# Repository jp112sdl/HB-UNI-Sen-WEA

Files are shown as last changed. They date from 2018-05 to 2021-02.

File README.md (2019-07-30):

# Selbstbau-868MHz-Funk-Wetterstation (mit Netzteilbetrieb) für HomeMatic  

### Die Dokumentation zu diesem Projekt findet ihr im -> [Wiki](https://github.com/jp112sdl/HB-UNI-Sen-WEA/wiki).

**Hinweise:**
  - **die aktuelle Version des Source-Codes setzt mind. [Addon Version V1.20](https://github.com/jp112sdl/HB-UNI-Sen-WEA/wiki/Addon) oder höher voraus!**
  - **vor dem Flashen des Codes immer auf die neueste AskSinPP(-master) Bibliothek aktualisieren**

Besten Dank an [Christoph Herrmann](https://www.facebook.com/hermi.leipzig) für die Zusendung seines Nachbaus ([Thingiverse-Link](https://www.thingiverse.com/thing:3173141)):
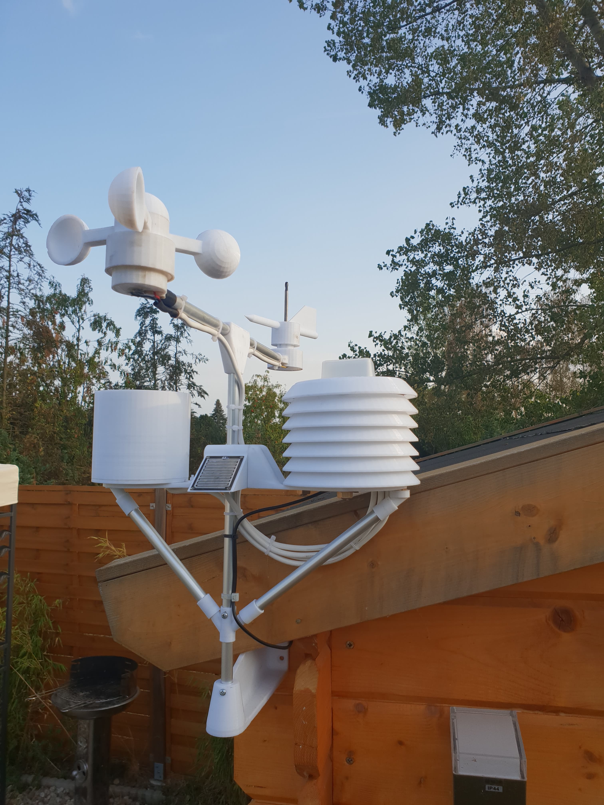
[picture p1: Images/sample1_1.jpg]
complete

<br/>
Hier meine Version unter Verwendung eines Huger Regenmengenmessers und noch vor der Installation des Regendetektors:
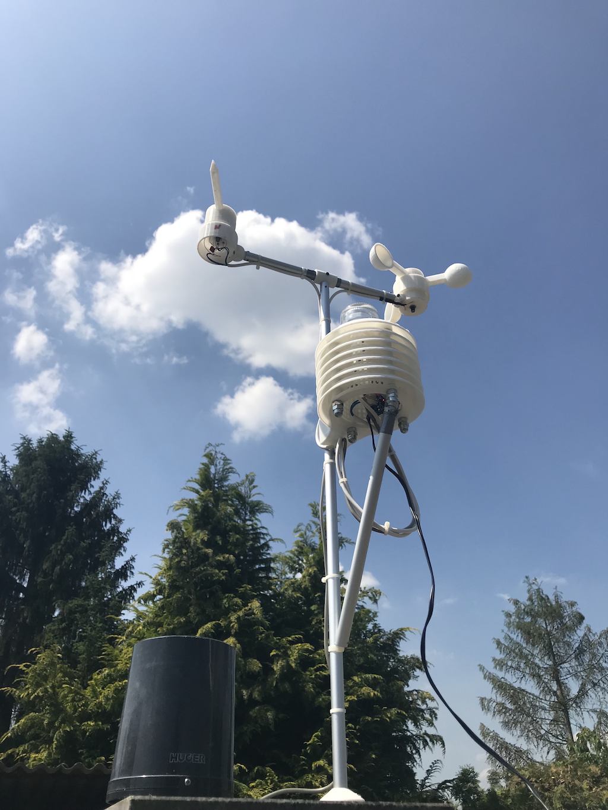
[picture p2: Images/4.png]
complete_jp


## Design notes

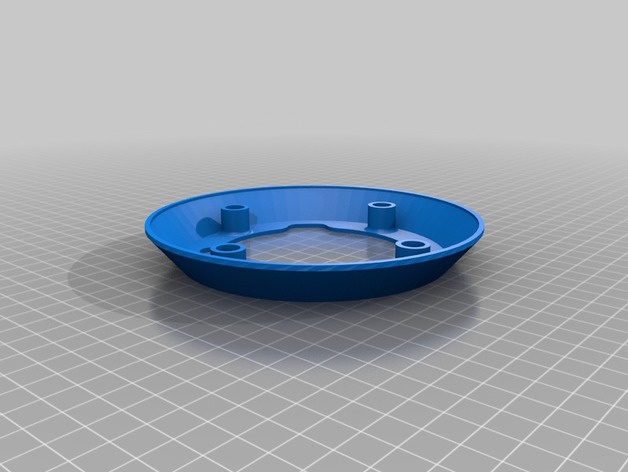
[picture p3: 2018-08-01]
3DDruck/Luftdaten_Stevensson_screen/images/de5c749b48ccad6f2da1c18631324c17_preview_featured.jpg

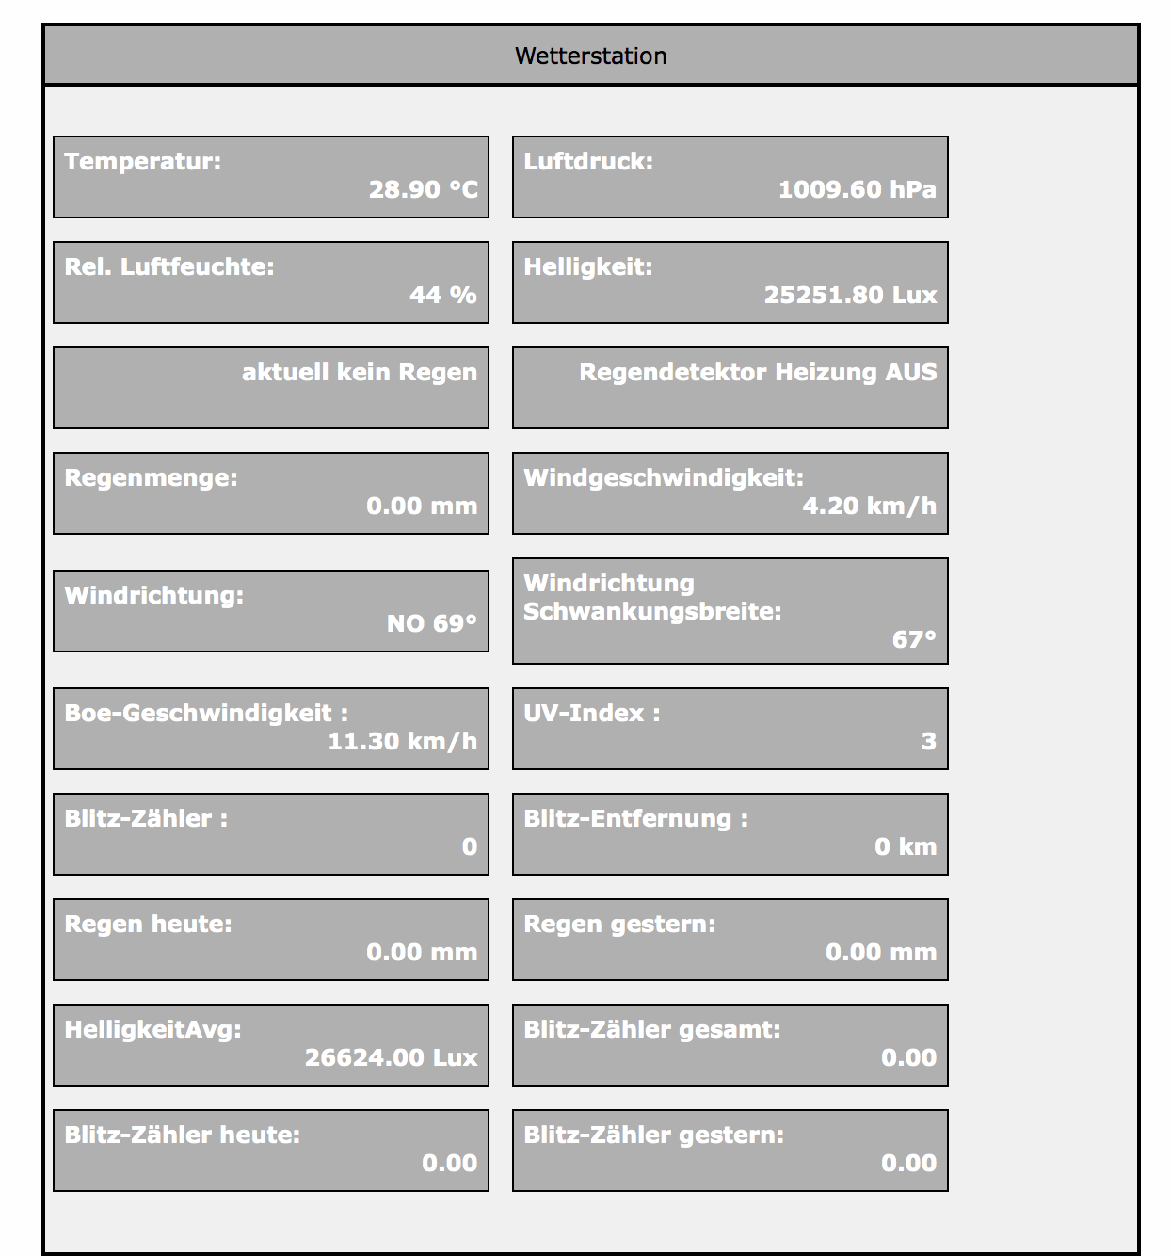
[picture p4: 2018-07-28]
Images/CCU_Bedienung.png

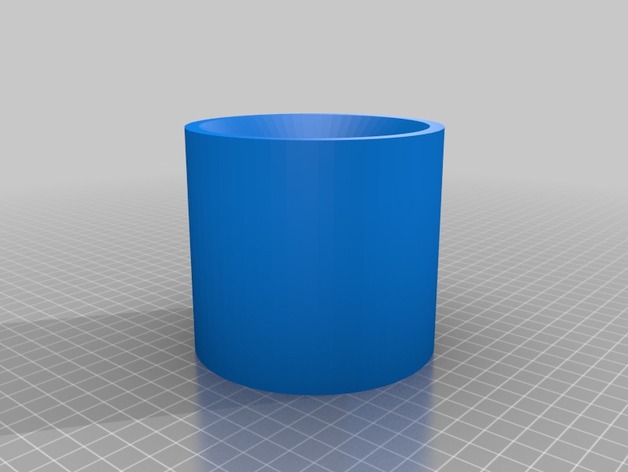
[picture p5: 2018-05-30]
3DDruck/LTB_Weather_Station/images/117a4e0169dc935ad4cb069c9b1e4cbd_preview_featured.jpg

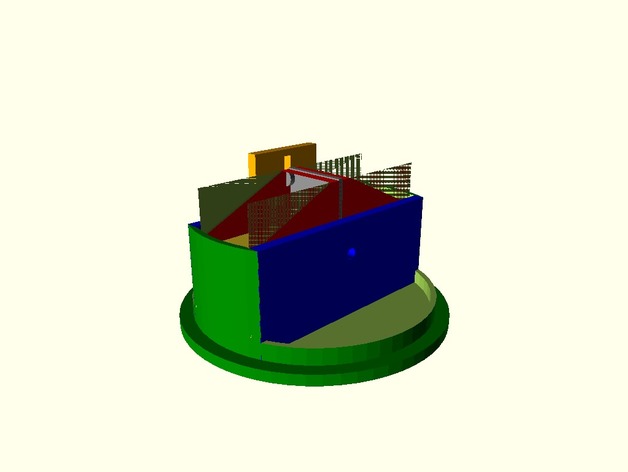
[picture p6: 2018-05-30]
3DDruck/LTB_Weather_Station/images/5851a940cc2cf8ce6b7ae1dae2f9f374_preview_featured.jpg

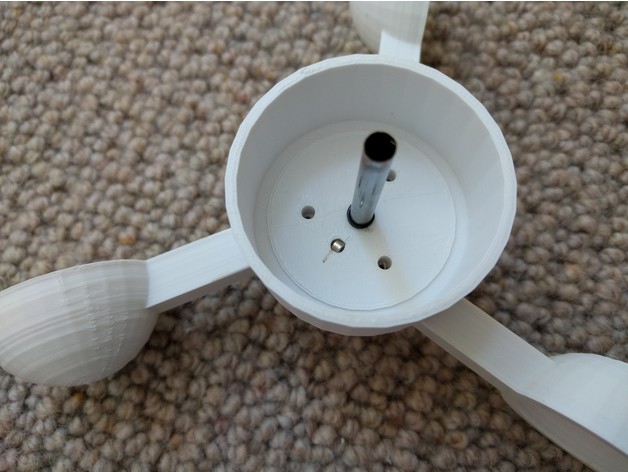
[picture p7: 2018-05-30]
3DDruck/LTB_Weather_Station/images/2c7b42b0f8cd26165a07a06924028e5b_preview_featured.jpg

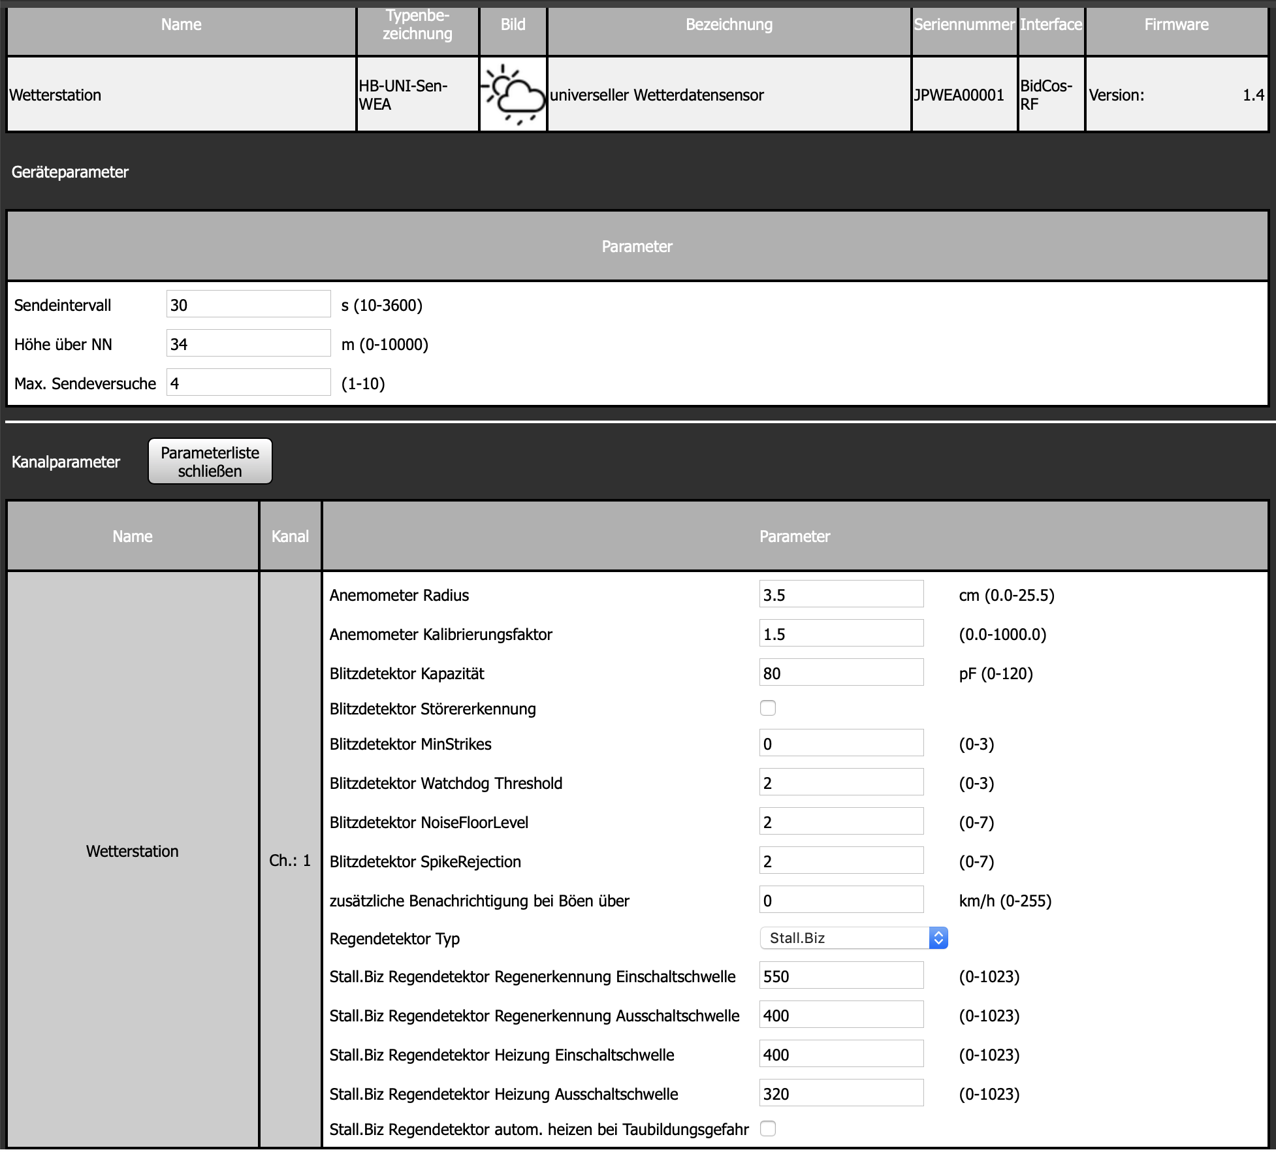
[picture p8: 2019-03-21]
Images/CCU_Einstellungen.png

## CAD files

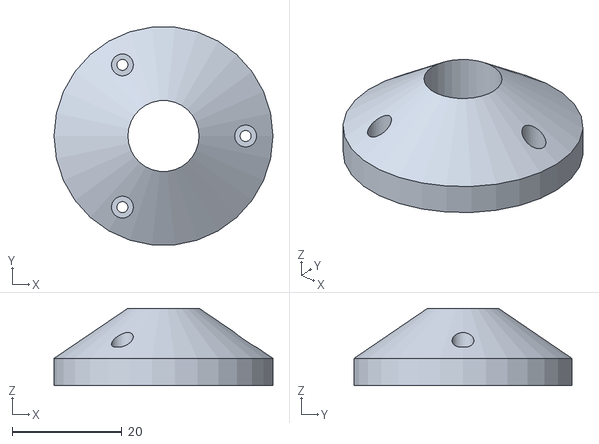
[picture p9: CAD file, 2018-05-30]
3DDruck/LTB_Weather_Station/files/42Fram_Base.stl
40.0 x 39.8 x 14.2

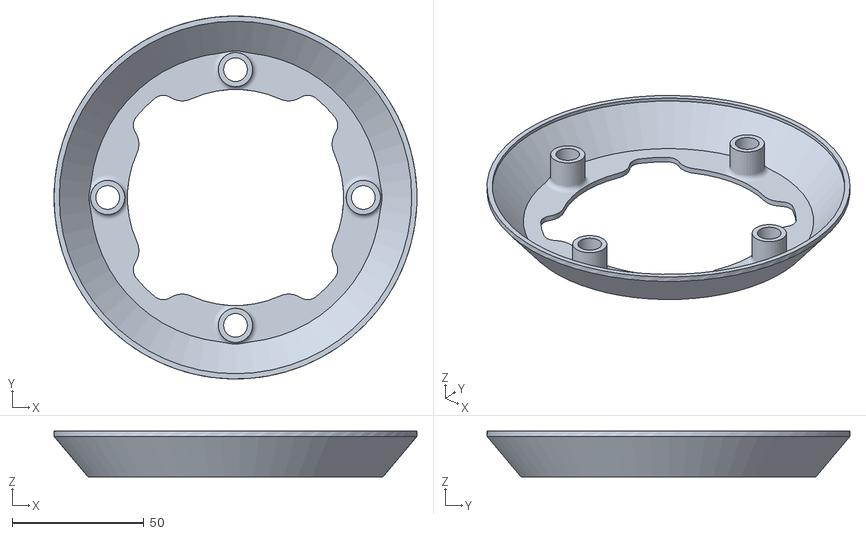
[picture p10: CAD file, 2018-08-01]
3DDruck/Luftdaten_Stevensson_screen/files/middle_part_x6.STL
137.7 x 137.7 x 17.3

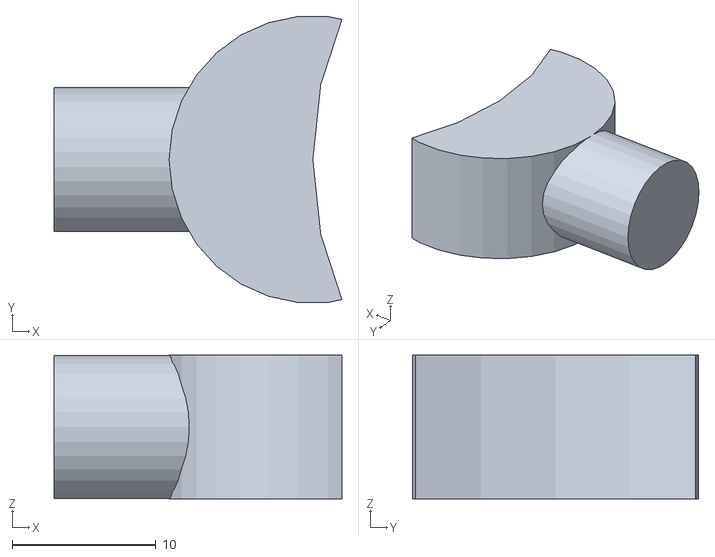
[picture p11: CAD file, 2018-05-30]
3DDruck/LTB_Weather_Station/files/13Direc_bracket.stl
20.0 x 19.9 x 10.0

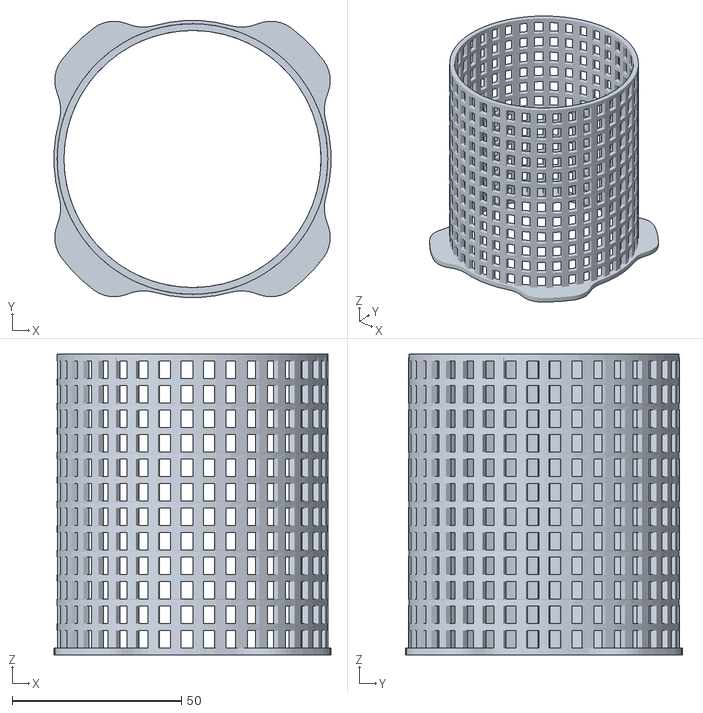
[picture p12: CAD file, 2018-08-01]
3DDruck/Luftdaten_Stevensson_screen/files/sds011_holder_x1.STL
81.9 x 81.9 x 89.0

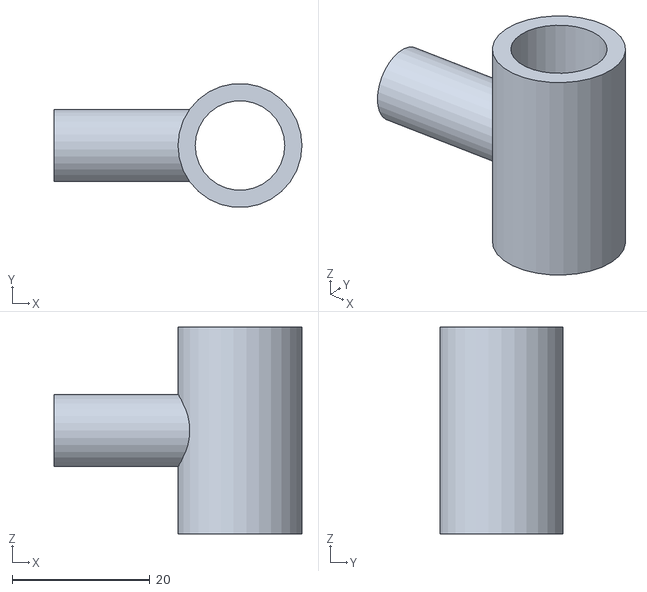
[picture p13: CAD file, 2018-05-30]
3DDruck/LTB_Weather_Station/files/41Fram_T_piece.stl
36.0 x 17.9 x 30.0

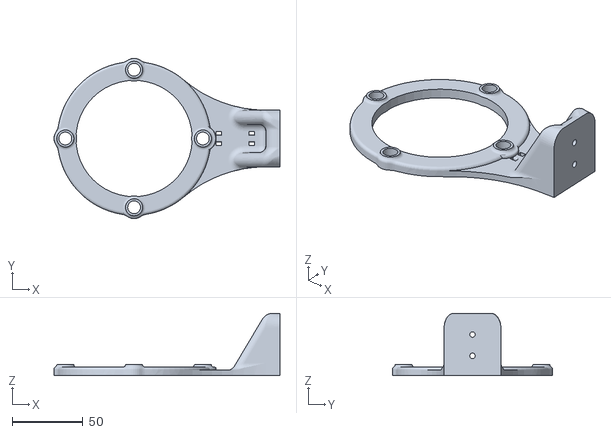
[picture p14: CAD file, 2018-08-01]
3DDruck/Luftdaten_Stevensson_screen/files/wall_bottom_part_x1.STL
159.3 x 112.9 x 44.0

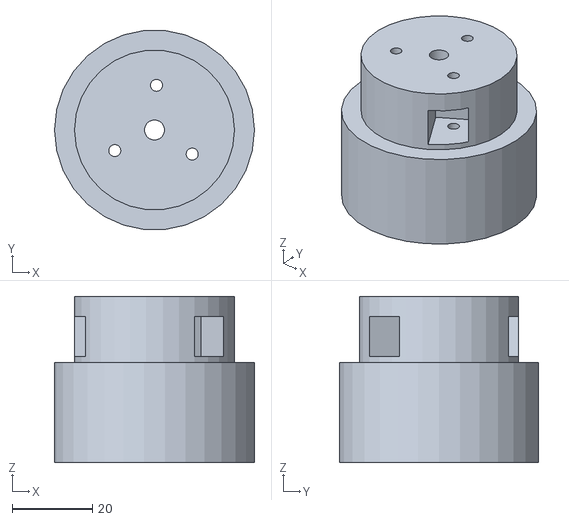
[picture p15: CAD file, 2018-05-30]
3DDruck/LTB_Weather_Station/files/02Anem_center.stl
50.0 x 49.7 x 41.5

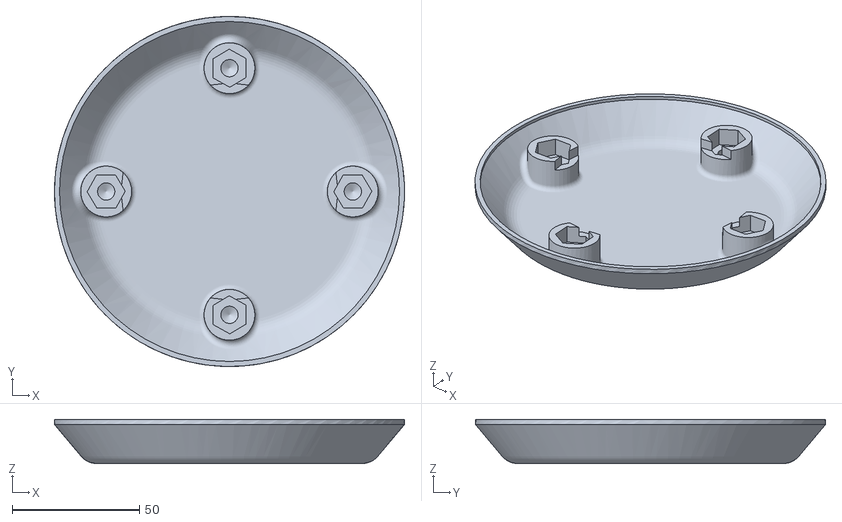
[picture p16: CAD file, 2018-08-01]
3DDruck/Luftdaten_Stevensson_screen/files/top_part_x1.STL
137.7 x 137.7 x 17.3

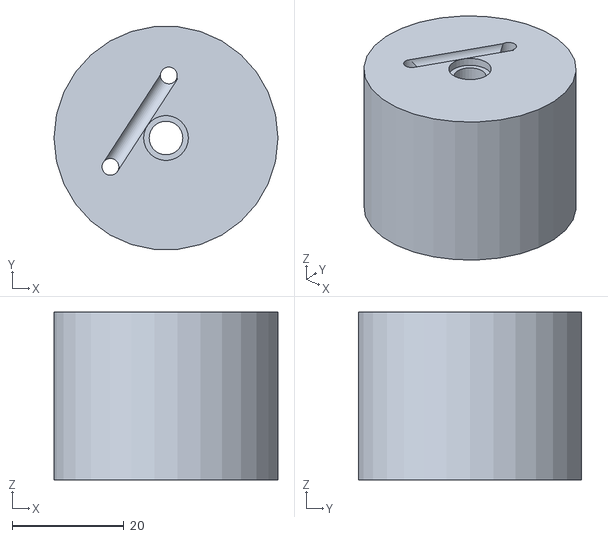
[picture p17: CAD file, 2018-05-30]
3DDruck/LTB_Weather_Station/files/03Anem_Base.stl
40.0 x 39.8 x 30.0

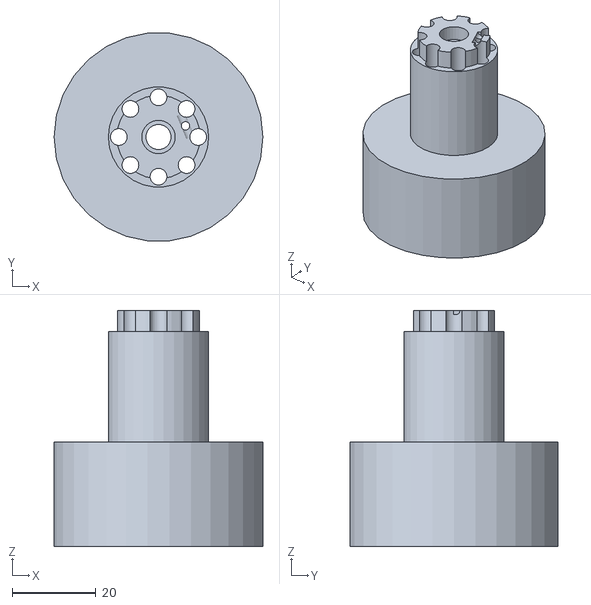
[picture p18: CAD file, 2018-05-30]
3DDruck/LTB_Weather_Station/files/12Direc_base.stl
50.0 x 49.7 x 56.5

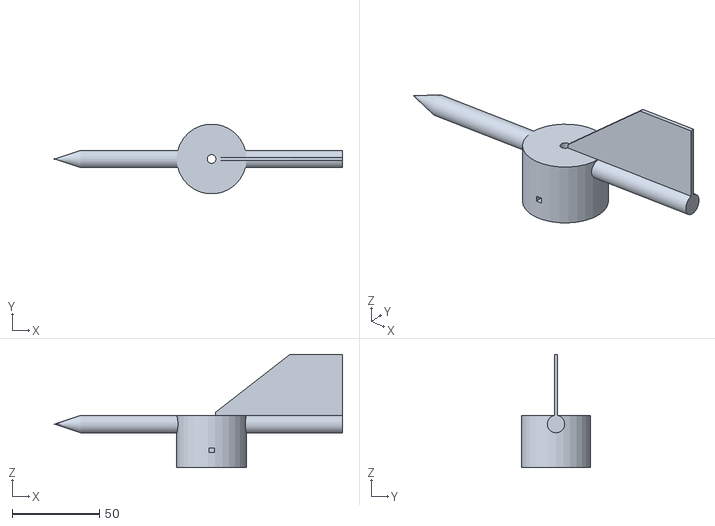
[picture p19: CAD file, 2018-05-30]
3DDruck/LTB_Weather_Station/files/11Direc_pointer.stl
165.0 x 39.8 x 65.0

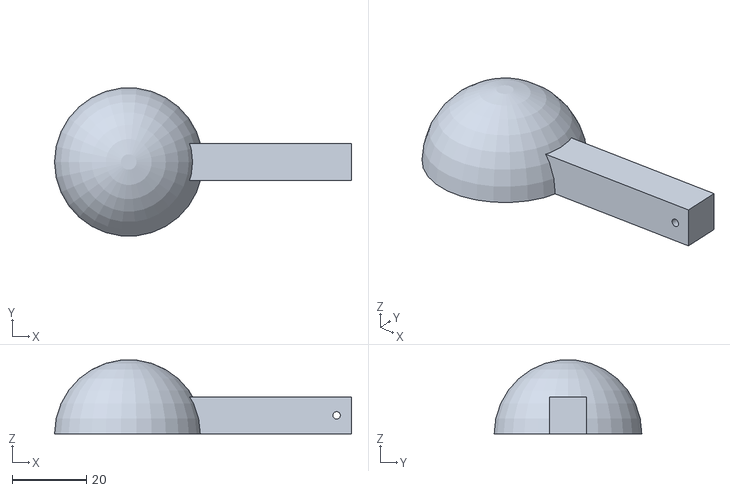
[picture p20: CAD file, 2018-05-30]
3DDruck/LTB_Weather_Station/files/01Anem_Cup.stl
80.0 x 39.8 x 19.9

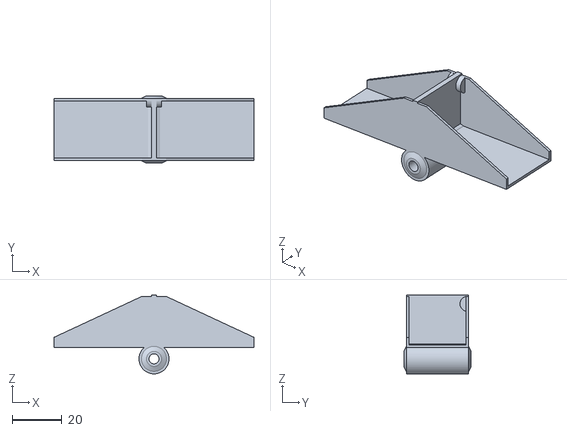
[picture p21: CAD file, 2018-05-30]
3DDruck/LTB_Weather_Station/files/31Rain_FlipFlop.stl
80.0 x 27.0 x 31.5

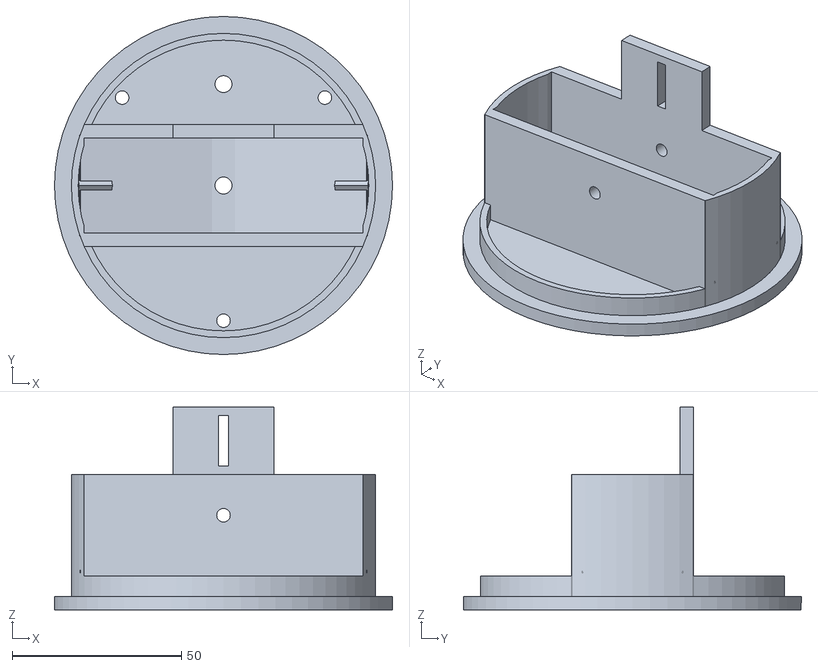
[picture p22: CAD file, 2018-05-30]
3DDruck/LTB_Weather_Station/files/32Rain_Base.stl
100.0 x 100.0 x 60.0

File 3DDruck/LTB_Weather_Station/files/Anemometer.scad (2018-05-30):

//LTB Weather in 3D
//Anemometer and Wind Direction

$fn=30;
//Non-Printable Extras
//Neodymium Magnet, cylinder  2mm thick, 3mm diam
//Red Switches, 14mm long 2mm diam
//Thrust bearings, 8mm OD, 5 mmID, 2.5mm thick
//Rods for the bearings 5mm OD, rescued brass antenna tubing is ideal!
//Heat shrink tubing to make a small sleeve to adjust height off bearings

//Make the shape of the front of the vane
module prism(l, w, h){
  polyhedron(
    points=[[0,0,0], [l,0,0], [l,w,0], [0,w,0], [0,w,h], [l,w,h]],
    faces=[[0,1,2,3],[5,4,3,2],[0,4,5,1],[0,3,4],[5,2,1]]
   );
}

module windvane(){
	difference(){
		union(){
			rotate([0,90,0]) cylinder(150,5,5,true); //main rod
			translate([-82.5,0,0])rotate([0,90,0]) cylinder(15,0,5,true); //pointy tip
			translate([45,-1,0]) cube([30,2,40]); //vane_1
			rotate([0,0,-90])  translate([-1,0,5]) prism(2,45, 35);//vane_2
			translate([0,0,-10]) cylinder(30,20,20,true); //mounting bracket
		}
		//This next dimension hollows the innner skirt of the windvane
		//It controls how close you can get the magnet to the reed switches
		//The magnet needs N-S to be vertical aligned with the reed switches
		//If it is not close enough or strong enough it will not reliably
		//trigger the both reed switches when positioned halfway between two.
		//This effect allows 16 directions to be obtained from 8 switches.
		//You may need to experiment a bit here to make it reliable.
		translate([0,0,-15]) cylinder(30,13.2,13.2,true); //mount cap inner
		cylinder(60,2.5,2.5,true); //mounting spindle axle hole 5mm diam 
		//magnet mount, radial distance is adjustable for multiple reed 'hits'
		//hitting 2 reed switches at a time doubles resolution from 8 to 16
		 translate([0,-11,-15]) rotate([0,0,90]) cube([20,3.1,2.6],true); 
	}
}

module dirbasesupport(){
  difference(){
   union(){
		translate([0,0,2.5]) cylinder(5,10,10,true); //axle mount top
 		color("red") translate([0,0,-15]) cylinder(30,12,12,true); //mount cap inner
	 translate([0,0,-39]) //move bottom skirt
	 difference(){
		 color("red") cylinder(25,25,25,true); //outer skirt
		 translate([0,0,-2]) cylinder(23,23,23,true); //inner skirt
	 }
	}
		cylinder(70,3,3,true); //spindle hole,6mm ID for 5mm axle
	  translate([0,0,3]) cylinder(4,4,4,true); //top hole for bearing
	  translate([0,0,-28]) cylinder(4,4,4,true); //bottom hole for bearing 	 	
		rotate([0,0,22.5]) translate([7,0,-10]) cylinder(60,1,1,true);//Relay common wire
		rotate([90,180,22.5]) translate([-7,-5,0]) cylinder(6,1,1,true);//Relay common wire
 
	   for(rrelay = [0 : 45 : 360])
		  //rotate([90,rrelay,0]) translate([25,10,0]) 
		rotate([0,0,rrelay]) translate([9.5,0,-10]) cylinder(60,2,2,true);//Relays mounts
	 }
}

//Print three of these separately
module cup(){
	color("blue")
	difference(){
		translate([-66,0,0]) //radiate from center
		difference(){
			union(){
				sphere(20); //outer wall
				translate([35,0,5]) cube([50,10,10],true); //support arm
			}
			sphere(17); //inner space
			translate([0,0,-10]) cube([40,40,20],true); //chop off what we don't need
		}
		rotate([90,0,0]) translate([-10,5,0])  cylinder(20,1,1,true); //screw mount
	}
}

module cups3mount(){
	difference(){
	union(){
		cylinder(20,20,20,true);
	 translate([0,0,-19]) //move bottom skirt
	 difference(){
		 cylinder(25,25,25,true); //outer skirt
		 translate([0,0,-2]) cylinder(23,23,23,true); //inner skirt
	 }
 }
		cups3(); //just used to create and align holes for cups
		rotate([0,0,174]) translate([-10,5,0]) cylinder(40,1.5,1.5,true); //screw mount
		rotate([0,0,54]) translate([-10,5,0]) cylinder(40,1.5,1.5,true); //screw mount
		rotate([0,0,294]) translate([-10,5,0]) cylinder(40,1.5,1.5,true); //screw mount
		cylinder(40,2.5,2.5,true);//spindle axle 5mm OD
		translate([0,-8,-10]) cube([2,3,4],true);//magnet hole, N-S is aligned tangential to circumference, ie magnetic force lines are along the switch reeds
		}
}	

//now combine all three into one module, to set up holes in mount base
module cups3(){
	rotate([90,0,0])cup();
	rotate([90,0,120])cup();
	rotate([90,0,240])cup();
}

module cuprotormount(){
	difference(){
		cylinder(30,20,20,true);
		rotate([0,0,54]) translate([-10,5,0]) cylinder(40,1.5,1.5,true); //reed relay mount
		rotate([0,0,294]) translate([-10,5,0]) cylinder(40,1.5,1.5,true); //reed relay mount
		rotate([0,90,57]) translate([-15,5.5,0]) cylinder(20,1.5,1.5,true); //reed relay slot for mounting

		cylinder(40,3,3,true);//6mm ID spindle bearing shaft, for a 5mm axle
	  translate([0,0,14.5]) cylinder(2,4,4,true); //top hole for bearing 8mmOD
	  translate([0,0,-14.5]) cylinder(2,4,4,true); //bottom hole for bearing 8mm OD
	}
}

//Glue this to the side of the speed indicator for a mouning option
module bracketSpeed(){
	difference(){	
		cylinder(10,10,10,true);
		translate([20,0,0]) cylinder(10,20,20,true);
	}
	translate([-13,0,0]) rotate([90,0,90,]) cylinder(10,5,5,true);
}

//Glue this to the side of the direction indicator for a mouning option
module bracketDirection(){
	difference(){	
		cylinder(10,10,10,true);
		translate([25,0,0]) cylinder(10,25,25,true);
	}
	translate([-13,0,0]) rotate([90,0,90,]) cylinder(10,5,5,true);
}

//Use this to mount the aluminium crossbar on a vertical aluminium tube
module Tpiece(){
	difference(){	
		union(){
			cylinder(30,9,9,true);
			translate([-17,0,0]) rotate([90,0,90,]) cylinder(20,5.25,5.25,true);
		}
		translate([0,0,0]) cylinder(30,6.5,6.5,true);
	}
}

//Vertical mount for the aluminium tube onto the baseboard
module Tframebase(){
	difference(){
		union(){
	translate([0,0,2.5]) cylinder(5,20,20,true);
	translate([0,0,10]) cylinder(10,20,5.25,true);
		}
	rotate([0,0,0,]) cylinder(30,6.5,6.5,true);
		
	 rotate([0,0,0]) translate([15,0,10]) cylinder(10,2,2,true);	
	rotate([0,0,120]) translate([15,0,10])cylinder(10,2,2,true);	
	rotate([0,0,240]) translate([15,0,10])cylinder(10,2,2,true);
		
	 rotate([0,0,0]) translate([15,0,10]) cylinder(30,1,1,true);	
	rotate([0,0,120]) translate([15,0,10])cylinder(30,1,1,true);	
	rotate([0,0,240]) translate([15,0,10])cylinder(30,1,1,true);	
}
}

module direction(){
difference(){
  union(){
		translate([0,0,6]) windvane(); //direction indicator
		translate([0,0,0]) dirbasesupport(); //mount for direction indicator
	}
	//translate([-220,0,-200]) cube([400,400,400]); //shows cutaway
 }
}

module speed(){
//cup(); //one cup, print three times
difference(){
union(){ 
	cups3(); //three cups in place, DO NOT print this
  cups3mount(); //mount support for cups
  translate([0,0,-28]) color("gold") cuprotormount(); //speed base and bearings holder
	}
		//translate([-220,0,-200]) cube([400,400,400]); //shows cutaway
}
}

//Rendering visually
//Use these to see the parts "in-situ"

//Wind Speed Parts
translate([-60,0,0]) speed();
//translate([-20,0,0]) bracketSpeed();

//Wind Direction Parts
//translate([60,0,0]) direction();
//translate([5,0,0]) bracketDirection();

//Mounting Frame Parts
//Tpiece();
//Tframebase();

//STL List (render each separately and export as .stl)

//Wind speed parts (Anemometer)
  //cup(); //print 3 of these
  //cups3mount();
  //cuprotormount();
	//bracketSpeed();
//Wind direction parts
	//windvane();
	//dirbasesupport();
	//bracketDirection();
//Frame parts
	//Tpiece();
	//Tframebase();

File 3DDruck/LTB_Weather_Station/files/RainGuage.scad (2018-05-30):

//LTB weather in 3D
//Bucket tipping rain-guage

//Non-Printable Extras
//Neodymium Magnet, cylinder  2mm thick, 3mm diam
//Red Switch, 14mm long 2mm diam
//Rod for the axle 1.5 mm OD, rescued brass antenna tubing is ideal!
//2 rings of plastic tubing to put on opposite ends of tipping bucket axle.

$fn=60;
hy=5;  //hysteresis
//Main support base for bucket, drainage and electronics
module Rbase(){
	difference(){
		color("green") union(){
			cylinder(4,50,50); //main base
			cylinder(8,45,45); //outer base rim
			translate([0,0,4]) cylinder(4,40,40); //main middle base
			translate([0,0,20]) cylinder(40,45,45,true); //main base outer cylinder
		}
		translate([0,0,25]) cylinder(40,43,43,true); //main base inner cylinder
		translate([30,26,0]) cylinder(20,2,2,true);  //base mounting/levelling hole
		translate([-30,26,0]) cylinder(20,2,2,true); //base mounting/levelling hole
		translate([0,-40,0]) cylinder(20,2,2,true);  //base mounting/levelling hole
		rotate([0,0,90]) cylinder(10,2.5,2.5,true);  //small water drainhole
		translate([0,30,0]) rotate([0,0,90]) cylinder(10,2.5,2.5,true);  //small wire exit hole
		translate([0,40,0]) rotate([0,90,90]) cylinder(20,2.5,2.5,true);  //small wire exit tunnel
	}
}
module Rffsupport(){
	color("blue")
	difference(){
		translate([0,0,20]) cube([82.5,4,40],true); //side support
		translate([0,0,23+hy]) rotate([90,0,0]) cylinder(5,2,2,true);//locating semi-circle
	}
}

module drainramps(){
	//drain the water our of the central hole
	color("yellow") translate([-23,0,8]) rotate([0,10,0])cube([39.5,30,1],true);
	color("yellow") translate([23,0,8]) rotate([0,-10,0])cube([39.5,30,1],true);
	//projections to stop lip of bucket being held by water tension
	color("red") translate([-38,0,11]) rotate([45,10,0])cube([10,2,2],true);
	color("red") translate([38,0,11]) rotate([45,-10,0])cube([10,2,2],true);
	
}

module Rrelaysupport(){
	//place the reed switch in the gap and heat the wires on it to melt into the 
	//plastic and hold it in place, or just glue it there.
	color("orange")
	difference(){
		translate([0,30,50]) cube([30,4,20],true); //Plate for mounting reed switch
		translate([0,30,50]) rotate([0,90,0]) cube([15,5,3],true); //hole for reed switch
	}
}

module Rmainbase(){
	difference(){
		Rbase();
	  translate([0,0,30]) cube([82.4,124,40],true);//big cutaway
	}
		translate([0,-16,0]) Rffsupport();
		translate([0,+16,0]) Rffsupport();
		translate([0,-14,0]) Rrelaysupport();
		drainramps();
}

//Flip Flop tipping bucket
module Rflipflop(){
	difference(){
		union(){
			difference(){
				//begin with
				translate([0,0,10]) color("red") cube([80,25,20],true); //main body
				//take these out
				translate([-20,0,35]) rotate([0,155,0]) cube([80,25,40],true); 
				translate([20,0,35]) rotate([0,-155,0]) cube([80,25,40],true); //subtract top half of cube
				translate([0,0,10]) color("red") cube([80,23,20],true); //main body
			}
		//add these in
		cube([80,25,1],true);	//the flat base of tipping cups
		color("gray")  translate([0,0,8]) cube([2,25,25],true); //divider plate
		translate([0,0,-hy]) rotate([90,0,0]) cylinder(25,6,6,true); //outer axle bearing
		translate([0,13,-hy])  rotate([90,0,0]) cylinder(1,3,3,true); //washer A
		translate([0,-13,-hy])  rotate([90,0,0]) cylinder(1,3,3,true); //washer B
		translate([0,13,-hy])  rotate([90,0,0]) cylinder(1,3,5,true); //washer A slope
		translate([0,-13,-hy])  rotate([90,0,0]) cylinder(1,5,3,true); //washer B slope
		color("grey")	translate([0,12,17]) rotate([0,90,0])cylinder(6,3,3,true); //support for the magnet	
			}
	//take these out	
	translate([0,0,-hy]) rotate([90,0,0]) cylinder(29,2,2,true); //inner axle
	translate([-5,12.5,12.5],true) cube([10,10,10]); //removes excess magnet support
	translate([0,12,17]) cube([4,3,2],true);//magnet hole, NB N-S is parallel to the reed switch, ie field lines run along the reed switches
		
	}
}

module funnel(){
	translate([0,0,5])
		difference(){
			color("red") cylinder(90,50,50); //main base
			cylinder(90,45,45); //main base
		}
	difference(){
		translate([0,0,55]) cylinder(40,2,48);
		translate([0,0,58]) cylinder(40,2,48);
		translate([0,0,55]) cylinder(10,2,2);
	}
}

//Main parts
Rmainbase();
translate([0,0,38-hy])	rotate([0,0,0]) Rflipflop(); //flip flop tipping
//Rflipflop();
difference(){
	//funnel();
	//uncomment for a "demonstration funnel" to show people how it works
	//rotate([0,0,90]) translate([10,-100,0]) cube([100,200,100]);  //for demo cutaway
}

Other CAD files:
3DDruck/LTB_Weather_Station/files/34Rain_PartFunnel.stl
3DDruck/LTB_Weather_Station/files/33Rain_Funnel.stl
3DDruck/LTB_Weather_Station/files/04Anem_bracket.stl

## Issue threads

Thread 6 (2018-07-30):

Schaltplan mit HB-UNI-SEN-PCB

Athemis, 2018-07-30:
Hallo,

ersteinmal ein großes Dankeschön für dieses inspirierende Projekt :) Aus den Bildern geht hervor, dass Du das HB-UNI-SEN-PCB von Alex Reinert verwendest? Wäre es möglich, dass Du in der Dokumentation auch die Verschaltung anhand dieses Boards einfügst? Ich bin mir sicher, dass ich mir das vermutlich (unter großer Fehleranfälligkeit) auch selbst zusammenreimen kann, aber wozu das Rad neu erfinden...

Besten Dank!

jp112sdl, 2018-07-30:
Mahlzeit!

Ja, ich habe dieses Board im Einsatz.
Aber ich würde es für **dieses** Projekt nicht empfehlen.
 _(Das Board an sich ist Klasse, wenn man ein paar I²C Sensoren und/oder analoge Eingänge nutzen möchte.)_
Aufgrund der mittlerweile von der ursprünglichen Wetterstation entstandenen Menge an Sensoren, reichen die auf dem Board ausgeführten Pins bei weitem nicht mehr aus, so dass ich den AS3935 teilweise und den Regendetektor bereits vollständig an die Pro Mini Pinleiste anlöten musste.

Vielleicht erstellt ja jemand ein Board, an das die verwendeten Sensoren komplett angeschlossen werden können. Darüber würde auch ich mich sehr freuen. 😄

LG,
Jérôme

Athemis, 2018-07-30:
Alles klar. Ich hatte beinahe befürchtet, dass nicht genügend Pins nach außen geführt werden. Da ich aber noch ein paar von den Boards hier herumfliegen habe, werde ich vermutlich dennoch eines als Grundlage nehmen und dann ggf. die Sensoren direkt am Arduino anflanschen :grinning:

LG, Alex

jp112sdl, 2018-07-30:
Spätestens wenn mir das 3. Mal die Drähte abgebrochen sind, denke ich noch mal über eine eigene Platine nach 🙄
Aber ich hoffe, dass sich nun nichts mehr an der Hardware ändert.
Vom 328P-Flash-Platz her ist eh kaum noch was frei und das Datentelegramm ist in seiner Länge auch aufs letzte Byte ausgereizt. Es wären maximal noch 1-2 logische Zustände, die übertragen werden könnte. Aber da fällt mir auch gerade nichts ein, was dafür infrage käme. 😃

☀️ Grüße ☀️

jp112sdl, 2018-07-31:
Ich habe gestern Abend noch ein wenig mit Alex geplaudert und er setzt sich mal ran, eine Platine für dieses Projekt hier zu entwerfen, bzw. die HB-UNI-SEN-PCB abzuändern.
Wenn es was Neues gibt, melde ich mich hier wieder.

Athemis, 2018-07-31:
Klasse, das wäre natürlich die optimale Lösung :) Ich bin schon sehr gespannt.

jp112sdl, 2018-08-08:
So, [hier](https://github.com/jp112sdl/HB-UNI-Sen-WEA/wiki/Platine) wäre dann das Ergebnis.
😄

Athemis, 2018-08-08:
Super! Dann weiß ich schon einmal, was es jetzt zu bestellen gilt... :smile:

jp112sdl, 2018-08-08:
Ich habe soeben einen Stapel in Auftrag gegeben.
Du kannst von mir eine (oder auch mehrere) zum Selbstkostenpreis + Versand bekommen (sobald sie eingetroffen sind).

Athemis, 2018-08-17:
Hatte zu dem Zeitpunkt selbst schon eine Hand voll geordert ;-)

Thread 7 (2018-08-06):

fehlende Libs

Xento, 2018-08-06:
Hi,
ich möchte mir auch soeine Wetterstation bauen und habe versucht den Sketch zu compilern.
Leider fehlen die Bibliotheken für
#include <sensors/Max44009.h>
#include <sensors/Veml6070.h>

Für Max44009 konnte wahrscheinlich die richtige Lib finden, allerdings will Veml6070 nicht.
Ich nutze die Arduino IDE zum compilern.
Könntest du Links zu den verwendeten Bibliotheken reinstellen?

jp112sdl, 2018-08-06:
Hi,

lade dir bitte mal die aktuelle master der AskSinPP Library.
Dort sind die Sensorklassen für den Max44009 und Veml6070 mit drin.
Es werden **keine** gesonderten Bibliothek benötigt.

Siehe auch: https://github.com/jp112sdl/HB-UNI-Sen-WEA/wiki/Code

Xento, 2018-08-06:
Ah super. Dann muss ich mal alles aktualisieren.

Closed 2018-08-06.

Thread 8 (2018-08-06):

Frage: Wie funktioniert die Böenerkenung

Xento, 2018-08-06:
Wie genau funktioniert die Böenerkennung?
Wird nur alle x Sekunden gemessen oder wird alle x Sekunden geprüft ob eine Böe da war?
Will damit meine Markiese bei Böen einfahren lassen.

jp112sdl, 2018-08-06:
5 Sekunden lang werden die Impulse gezählt und daraus die Geschwindigkeit ermittelt.
Die Windgeschwindigkeit hingegen ist der Mittelwert aller "5-Sekunden-Geschwindigkeiten", die im eingestellten Sendeintervall ermittelt wurden.

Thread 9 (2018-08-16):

BIDI bei WeatherEventMsg?

Xento, 2018-08-16:
Ist er richtig so, dass die WeatherEventMsg bidirektional gesendet werden?
Seitdem ich einen Windsensor gebaut habe ist auch bei 60 sekündiger Meldung der DC der CCU ziehmlich angestiegen.
Will mir noch einen zweiten Wettersensor mit allen Sensoren bauen, dann währe die CCU schon ziehmlich an ihrere Grenze.

jp112sdl, 2018-08-16:
Echt? 😱
Ich sende alle 30 Sekunden und da passiert nix am DC.
Eigentlich wird nur jede [20. Meldung per BIDI gesendet, sonst per BCAST](https://github.com/jp112sdl/HB-UNI-Sen-WEA/blob/7250f011d05615f5691bec8c287be622bd283e45/HB-UNI-Sen-WEA.ino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).
Oder hab ich einen Denkfehler?

Aber bei mir liegt der DC konstant zwischen 5-9%

jp112sdl, 2018-08-16:
![Uploading Bildschirmfoto 2018-08-16 um 10.51.04.png…]()

Habs gerade noch mal gecheckt. Arbeitet korrekt.

Xento, 2018-08-16:
Ok, soweit hab ich noch nicht in den Code geschaut.
Hatte nur das BIDI bei der Message gesehen.
Das BIDI wird zurückgesetzt wenn man das per broadcast sendet.
Dann muss ich mal weiter rumprobieren warum der DC nun so hoch ist bei mir ...

jp112sdl, 2018-08-16:
Ja genau, `broadcastPeerEvent()` sendet automatisch per BCAST.

Closed 2018-08-16.

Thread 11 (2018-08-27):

Kalibrierung für Ersatz-Anemometer für die Funk-Wetterstation WS1080 und WS3080

Xento, 2018-08-27:
Ich habe mal die Kalibrierungsdaten für das oben genannte Ersatzteil von ELV ausgeklügelt.
Die Daten habe ich mit Hilfe der Freetec Wetterstation von Pearl ermittelt.
Diese ich bis auf das Funkprotokoll baugleich mit der WS1080, daher ist es auch das gleiche Windrad.

Damit immer der gleiche Wind auf das Windrad trifft, habe ich das Anemometer abwechselnd mit der Wetterstation und dem Homematic Sensor verbunden und die Werte verglichen.
Folgende Werte sind dabei rausgekommen:
Radius: 7 cm
Kalbrierungsfaktor: 1.5

Vielleicht kann man eine Liste mit Werten für verschiedene Anemometer bereitstellen.
Wenn jemand keinen Windmesser oder eine andere Referenz hat, ist es quasi unmöglich die richtigen Werte zu finden.

jp112sdl, 2018-08-27:
Besten Dank! Bin noch am Überlegen, wo ich diese Informationen am besten platziere...

jp112sdl, 2018-08-28:
https://github.com/jp112sdl/HB-UNI-Sen-WEA/wiki/Kalibrierungsdaten_Sensoren

Closed 2018-08-28.

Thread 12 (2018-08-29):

Nachrichten werden mit NACK von anderem AsksinPP-Aktor beantwortet

Xento, 2018-08-29:
Ich habe gerade zufällig festgestellt, dass irgendwie komische Nachrichten gesendet werden.

Der Wettersensor ist mit meinem RolloAktor (auch mit AskSinPP) gepeert so dass dieser runter fährt wenn ne Windböhe kommt.

Hier ein Auszug aus der Log vom Rolloaktor:
```
-> 0D 05 A0 53 F1D002 5932AF 41 00 00 C7  - 254183
<- 0A 05 80 02 5932AF F1D002 80  - 254298
-> 0D 05 A0 53 F1D002 5932AF 41 00 00 C7  - 254337
<- 0A 05 80 02 5932AF F1D002 80  - 254459
-> 0D 05 A0 53 F1D002 5932AF 41 00 00 C7  - 254498
<- 0A 05 80 02 5932AF F1D002 80  - 254619
-> 0D 05 A0 53 F1D002 5932AF 41 00 00 C7  - 254652
<- 0A 05 80 02 5932AF F1D002 80  - 254769
-> 0D 05 A0 53 F1D002 5932AF 41 00 00 C7  - 254803
<- 0A 05 80 02 5932AF F1D002 80  - 254918
-> 0D 05 A0 53 F1D002 5932AF 41 00 00 C7  - 254957
<- 0A 05 80 02 5932AF F1D002 80  - 255078
-> 0C 06 A2 41 F1D002 5932AF 01 01 C8  - 255281
jumpToTarget: 6 1
setDestLevel: 0
Switch from 06 to 04
getNextState: 4
Switch from 04 to 05
<- 0E 06 80 02 5932AF F1D002 01 01 00 40 58  - 255401
getNextState: 5
calcDriveTime: 420 - 0 - 20
Switch from 05 to 09
DOWN - 255823
getNextState: 9
Switch from 09 to 06
STOP - 257853
```

Der Asksin Aktor schickt scheinbar irgendwas falsches auf diese Nachricht zurück ...

Xento, 2018-08-29:
Ah ich habe gerade festgestellt, das 0A 05 80 02 5932AF F1D002 80 ein NACK ist.
Das währe jetzt was für @pa-pa aber sollte, danach nicht weiter versucht werden die Nachricht erneut zu senden?

jp112sdl, 2018-08-29:
Hmm, wäre es dann evtl. eher ein Ticket für die AskSinPP Lib?

Von der Wetterstation kommt als COND_VALUE `C8` (200).

Ich hab die Wetterstation bisher nur mit einem originalen HM Zwischenstecker gepeert und da ist das Verhalten korrekt.

Falls du die Möglichkeit hast, könntest du als Gegenprobe mal einen Tastensender peeren. Der verhält sich m.W. genau so und sendet 200 an den Aktor.
Dann könntest du dort mal schauen, wie der Reply vom Rollladenaktor aussieht.

jp112sdl, 2018-08-29:
Ich wollte gerade fragen, welchen Stand dein eingesetzter Wetterstations-Sketch hat 😄
Denn der geht nur, wenn du die aktuelle AskSinPP nutzt mit eben genanntem Commit.
Die ExtraMessages werden seither nämlich nur noch direkt an die Zentrale gesendet.

Xento, 2018-08-29:
Werd ich morgen mal machen ;-)

Xento, 2018-08-30:
Soo, AskSinPP war schon auf dem aktuellen Stand, nur der Sketch nicht.

Hab da noch nen paar Offtopic Punkte:
1. Ich sollte mich glaube ich mal mit dem OTA-Bootloader beschäftigen, dann muss ich mich nicht immer an die Geräte stöpseln.
Funktioniert das eigentlich mit der CCU?

2. Mir ist aufgefallen, dass der Sketch für einen Arduino mit dem normalen Bootloader zu groß ist.
Die IDE sagt es währen 102% belegt.
Wenn man das Debugging deaktiviert dann sind noch 93% frei.
Zum Glück habe ich auf diesem Arduino schon den OptiBootloader drauf.

jp112sdl, 2018-08-30:
> Ich sollte mich glaube ich mal mit dem OTA-Bootloader beschäftigen, dann muss ich mich nicht immer an die Geräte stöpseln.
Funktioniert das eigentlich mit der CCU?

Ja, aber ob der Arduino per Funkbefehl in den Bootloader-Modus wechselt, weiß ich nicht.
Ich habe da nichts weiter implementiert und auch bisher nur 1-2 Mal mit OTA experimentiert.
Da ich gern nach dem Flashen noch kurz die Debugmeldungen sehen möchte, bleibe ich bei der Turnschuhvariante. 😄

> Mir ist aufgefallen, dass der Sketch für einen Arduino mit dem normalen Bootloader zu groß ist. Die IDE sagt es währen 102% belegt.

Welche Arduino IDE Version benutzt du?
Mit der 1.8.5 wird der Sketch zu groß. Ich nutze die 1.8.1 -> damit passt alles. Ohne Veränderung des Bootloaders.

> Wie bringt man der CCU bei, dass das Gerät eine neue Firmwareversion hat?
Musste nachdem ich das Addon aktualisiert hatte, den Sensor einmal ablernen und wieder anlernen.

Drüberlernen würde ausreichen, um die Versionsinformation an sich upzudaten.
Aber wenn neue Werte-Parameter hinzukommen, bleibt leider nix weiter übrig, als das Gerät komplett neu anzulernen. Das ist aber ein "Problem" der ReGa.

Closed 2018-09-04.

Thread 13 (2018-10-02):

slightly better parameter check of pwmval overflow in raindetector_heater

harvey637, 2018-10-02:
Hallo Jerome,
ist das optimal?

in funktion raindetector_heater:
...
if (State == true) {
  if pwmval < 255) pwmval = pwmval + 51;
} else
...

Alles richtig, es wird bei jedem Durchlauf pwmval um 51 erhöht, also 0 - 51 - 102 - 153 - 204 - 255.
Also passt < 255, weil ja nach dem 5. Durchlauf keine Erhöhung mehr stattfindet.

Will man da spielen könnte ein "#define PWMHEATER_DELTA 51" das ganze variabel gestalten,
also den Anstieg der Erwärmung z.b. flacher einstellen. Dann spätestens wäre es besser, etwa mit

#define PWMHEATER_DELTA 30 // zusätzliche Erwaermung der Regendetektorheizung je Durchlauf
(RAINDETECTOR_CHECK_INTERVAL)

...
if ((pwmval + PWMHEATER_DELTA) > 255) {
   pwmval = 255;
} else {
   pwmval = pwmval + PWMHEATER_DELTA;
}
...

das ganze (im Sketch) konfigurierbar und korrekt geprüft zu gestalten.
Sorry, sind wieder ein paar Byte mehr :-( Aber auch ohne define finde ich das if ... then ... else besser.
cu
Harvey

jp112sdl, 2018-10-02:
Ja, das kann jeder spielen wie er möchte.
Grundanliegen der PWM-Ansteuerung war, dass die Spannung beim Einschalten der Heizung nicht einbricht.

Btw.: Würde die Bedingung `(pwmval + PWMHEATER_DELTA) > 255` überhaupt erfüllt werden, so lange `pwmval` ein `uint8_t` ist?

Und wegen der paar Byte mehr -> wenn man einen kleineren (oder gar keinen) Bootloader auf den Pro Mini flasht, hat man noch gut Luft nach oben.

harvey637, 2018-10-02:
Hallo Jerome,
danke für die schnelle Antwort!

Vermutung: das "pwmval + PWMHEATER_DELTA" ist erstmal unabhängig von uint_8, ich test das mal, nur zum eigenen Verstandnis.

Genauso habe ich das mit dem langsamen Anheizen auch vermutet (Grund für ansteigenden PWM).
Eine Kleinigkeit fällt mir noch ein:
Könnte es sinnvoll sein, die zeitliche Länge des Heizens zu beschränken? Eventuell
liegt ein Blatt drauf oder eine Frucht ist drauf gefallen und geplatzt. Auch der Taupunkt könnte
ziemlich lange im HEAT_DEWFALL_T bleiben. In der Summe sicherlich verschmerzbar (Stromkosten),
aber der Sensor freut sich bestimmt drüber. Ich denke für mich auch über einen reinen
Regensensor nach, der dann ohne device.xml funktioniert und Heizung per Funk
geschaltet werden kann, ein von xxx Projektchen.
Neben dem (erfolgreich abgeschlossenen) LCD-Anzeige von Temperatursensoren und dem
ebenfalls (aber sehr quick_n_dirty) abgeschlossenen Dallas-Sensoren mit SENSOR_ID (aus user_byte)
anstatt der SENSOR_ADDR. Beispiele dazu in DallasTemperature gefunden.
Danke und ciao
Harvey

jp112sdl, 2018-10-02:
> Könnte es sinnvoll sein, die zeitliche Länge des Heizens zu beschränken?

Ist mir bisher noch gar nicht in den Sinn gekommen.

> aber der Sensor freut sich bestimmt drüber.

Mit ~50°C von unten dauerhaft beheizt zu werden, ist denke ich kein Problem für die Platine.

>  Auch der Taupunkt könnte ziemlich lange im HEAT_DEWFALL_T bleiben.

Ja, manchmal die halbe Nacht bei mir. Aber dann bleibt halt die Heizung an. Ist mir lieber, als eine Regen-Falschmeldung (die ich bisher noch **nie** hatte!) zu bekommen.

>  Ich denke für mich auch über einen reinen
Regensensor nach, der dann ohne device.xml funktioniert und Heizung per Funk
geschaltet werden kann, ein von xxx Projektchen.

Ja, sollte kein Problem sein den HM-Sen-RD-O nachzubilden.
Und der hat ja einen Kanal zum Schalten der Heizung.

Closed 2018-10-02.

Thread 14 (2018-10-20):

Abdeckung für UV Sensor VEML6070

spaceduck518, 2018-10-20:
wie habt ihr die die wasserfeste Abdeckung für den UV Sensor realisiert? Alle mir bekannten transparenten Kunststoffe filtern UV Strahlung, da dürfte am Sensor nicht mehr viel ankommen.

jp112sdl, 2018-10-20:
Hi,

für allgemeine Diskussionen bitte das Homematic Forum benutzen.
Es gibt hier einen Beitrag zum dem Wettersensor:
https://homematic-forum.de/forum/viewtopic.php?f=76&t=44245&start=390
Du kannst auch gern einen neuen Beitrag erstellen.

Hier erreichst du vorrangig nur mich als Entwickler...
Ich benutze eine kleines Gewürzglas.
Gabs mal als Adventkalender:
https://www.discounto.de/Angebot/Erlesene-Gewuerz-Selection-Adventskalender-955697/

LG,
Jérôme

Closed 2018-10-20.

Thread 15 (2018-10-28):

Regenmelder Sensorplatine anschließen

Alveran81, 2018-10-28:
Hallo,

bin gerade dabei die Wetterstation nachzubauen. Habe zunächst Arduino, BME280, CC1101 und Anemometer angeschlossen und einen Funktionstest gemacht. Werte kommen sauber auf der Homematic an.
Ich habe mir wie empfohlen diesen Regensensor gekauft. https://www.stall.biz/produkt/regenmelder-sensorplatine
Leider finde ich keinen Anschlussplan oder technische Daten. Wird dieser mit 5V betrieben und wie verbinde ich den Arduino damit?  Laut Schaltplan steht was von Pin9. Soll ja nicht die ganze zeit beheizt werden sondern nur wenn es regnet.
Also verstehe ich richtig, Dauerplus liegt immer an, die Masse für über den Transistor der an Pin neun hängt geschalten und dann müssen doch eigentllich noch zwei Messleitung verbunden werden?
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

jp112sdl, 2018-10-28:
Hi,

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

Es geht der
- **rot-weiße** Draht an **+ Heizung**, der
- **orange-weiße** an **- Heizung**,
- **schwarz** (GND) an **A vom Sensor** und
- **orange** geht an **B vom Sensor**.

Bei der Heizung wird wie schon richtig erkannt, +5V dauerhaft anliegen und die Heizung über den NPN Transistor an Pin 9 bei Bedarf eingeschaltet.

Alveran81, 2018-10-28:
Jetzt habe ich es verstanden. Vielen Dank.
Vielleicht kann man das in der Grafik noch ergänzen (schwarz (GND) an A vom Sensor und
orange geht an B vom Sensor.)

jp112sdl, 2018-10-28:
Ich dachte, die Grafik (Sensorfläche an schwarz/orange) wäre ausreichend. ;)

Alveran81, 2018-10-28:
War mir nicht ganz klar und da ich kein Datenblatt zum Sensor gefunden habe wollte ich lieber nochmal fragen bevor es einmal kurz raucht. 😁

jp112sdl, 2018-10-28:
A und B sind nicht leitend miteinander verbunden, da kann nix passieren.
Bei der Heizung passiert bei Verpolung einfach gar nix... 😄

Closed 2018-10-29.

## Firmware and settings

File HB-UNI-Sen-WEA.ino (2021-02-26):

//- -----------------------------------------------------------------------------------------------------------------------
// AskSin++
// 2016-10-31 papa Creative Commons - http://creativecommons.org/licenses/by-nc-sa/3.0/de/
// some parts (BME280 measurement) from HB-UNI-Sensor1
// 2018-05-11 Tom Major (Creative Commons)
// 2018-05-21 jp112sdl (Creative Commons)
//- -----------------------------------------------------------------------------------------------------------------------
// #define NDEBUG   // disable all serial debuf messages
// #define NSENSORS // if defined, only fake values are used
#define SENSOR_ONLY

#define  EI_NOTEXTERNAL
#include <EnableInterrupt.h>
#include <SPI.h>
#include <AskSinPP.h>
#include <Register.h>

#include <MultiChannelDevice.h>
#include <sensors/Max44009.h>
#include <sensors/Veml6070.h>
#include "Sensors/Sens_Bme280.h"
#include "Sensors/Sens_As3935.h"
#include "Sensors/Sens_As5600.h"
#include "Sensors/VentusW132.h"
//#include "Sensors/PCF8574_WindDir.h"

#define CONFIG_BUTTON_PIN                    8     // Anlerntaster-Pin

////////// REGENDETEKTOR
//bei Verwendung der Regensensorplatine von stall.biz (https://www.stall.biz/produkt/regenmelder-sensorplatine)
#define RAINDETECTOR_STALLBIZ_SENS_PIN       A3   // Pin, an dem der Kondensator angeschlossen ist (hier wird der analoge Wert für die Regenerkennung ermittelt)
#define RAINDETECTOR_STALLBIZ_CRG_PIN        4    // Pin, an dem der Widerstand für die Kondensatoraufladung angeschlossen is
#define RAINDETECTOR_STALLBIZ_HEAT_PIN       9    // Pin, an dem der Transistor für die Heizung angeschlossen ist
#define RAINDETECTOR_STALLBIZ_HEAT_DEWFALL_T 20   // Temperaturschwelle bei aktiviertem "automatisch Heizen bei Erreichen des Taupunkts"; default = 20 (heizen bei +/- 2,0°C um den Taupunkt)

//bei Verwendung eines Regensensors mit H/L-Pegel Ausgang
#define RAINDETECTOR_PIN                     9    // Pin, an dem der Regendetektor angeschlossen ist
#define RAINDETECTOR_PIN_LEVEL_ON_RAIN       LOW  // Pegel, wenn Regen erkannt wird

#define RAINDETECTOR_CHECK_INTERVAL          5     // alle x Sekunden auf Regen prüfen
/////////////////////////////////////////////////////////////////////

#define WINDSPEEDCOUNTER_PIN                 5     // Anemometer
#define RAINQUANTITYCOUNTER_PIN              6     // Regenmengenmesser


#define AS3935_ENVIRONMENT                   ::Sens_As3935<>::AS3935_ENVIRONMENT_OUTDOOR
#define AS3935_IRQ_PIN                       3     // IRQ Pin des Blitzdetektors
#define AS3935_CS_PIN_OR_ADDR                7     // SPI: CS Pin / I2C: Address (default: 0x03)

#define WINDDIRECTION_PIN                    A2    // Pin, an dem der Windrichtungsanzeiger (RESISTORS oder PULSE) angeschlossen ist
#define WINDDIRECTION_USE_RESISTORS
//#define WINDDIRECTION_USE_PULSE

//#define WINDDIRECTION_USE_AS5600
//#define WINDDIRECTION_USE_PCF8574

//#define WINDDIRECTION_USE_VENTUSW132
//#define VENTUSW132_PIN_N                     A0    // Pins für den Anschluss der
//#define VENTUSW132_PIN_O                     A1    // 4 Photodioden
//#define VENTUSW132_PIN_S                     A2    // des Ventus W132
//#define VENTUSW132_PIN_W                     A6    // Ersatz-Windmessers

//                             N                      O                           S                           W
//entspricht Windrichtung in ° 0 , 22.5 , 45 , 67.5 , 90 , 112.5 , 135 , 157.5 , 180 , 202.5 , 225 , 247.5 , 270 , 292.5 , 315 , 337.5
#ifdef WINDDIRECTION_USE_PULSE
const uint16_t WINDDIRS[] = { 70 ,   78 , 86 , 94   , 102,  108  , 116 ,    0  , 8   , 16    , 24  , 32    , 40  ,   48  , 56  , 62 };
#endif
#ifdef WINDDIRECTION_USE_RESISTORS
const uint16_t WINDDIRS[] = { 58 ,   74 , 52 , 115  , 97 ,  328  , 302 ,  790  , 559 , 663   , 187 , 205   , 163 ,  420  , 129 , 153 };
#endif
#if defined(WINDDIRECTION_USE_VENTUSW132) || defined(WINDDIRECTION_USE_PCF8574)
           //direction index  0   1   2    3    4    5    6    7
const uint16_t WINDDIRS[] = { 0, 45, 90, 135, 180, 225, 270, 315 };
#endif
#ifdef WINDDIRECTION_USE_AS5600
const uint16_t WINDDIRS[] = {0,0,0,0,0,0,0,0,0,0,0,0,0,0,0,0};
#endif

#define WINDSPEED_MEASUREINTERVAL_SECONDS    5     // Messintervall (Sekunden) für Windgeschwindigkeit / Böen
//////////////////////////////////////////////////////////////////////////////////////////////////////////////////////////////////////////


//some static definitions
#define WINDSPEED_MAX              0x3FFF
#define GUSTSPEED_MAX              0x7FFF
#define RAINCOUNTER_MAX            0x7FFF
#define STORM_COND_VALUE_LO        100
#define STORM_COND_VALUE_HI        200
#define PEERS_PER_CHANNEL          4

using namespace as;

volatile uint32_t _rainquantity_isr_counter = 0;
volatile uint16_t _wind_isr_counter = 0;

void rainquantitycounterISR() {
  _rainquantity_isr_counter++;
}
void windspeedcounterISR() {
  _wind_isr_counter++;
}

enum eventMessageSources {EVENT_SRC_RAINING, EVENT_SRC_HEATING, EVENT_SRC_GUST};

const struct DeviceInfo PROGMEM devinfo = {
  {0xF1, 0xD0, 0x02},        // Device ID
  "JPWEA00002",           	 // Device Serial
  {0xF1, 0xD0},            	 // Device Model
  0x14,                   	 // Firmware Version
  as::DeviceType::THSensor,  // Device Type
  {0x01, 0x01}             	 // Info Bytes
};

// Configure the used hardware
typedef AskSin<NoLed, NoBattery, Radio<LibSPI<10>, 2>> Hal;
Hal hal;

class WeatherEventMsg : public Message {
  public:
    void init(uint8_t msgcnt, int16_t temp, uint16_t airPressure, uint8_t humidity, uint32_t brightness, bool israining, bool isheating, uint16_t raincounter,  uint16_t windspeed, uint8_t winddir, uint8_t winddirrange, uint16_t gustspeed, uint8_t uvindex, uint8_t lightningcounter, uint8_t lightningdistance) {
      Message::init(0x1a, msgcnt, 0x70, BIDI | RPTEN, (temp >> 8) & 0x7f, temp & 0xff);
      pload[0] = (airPressure >> 8) & 0xff;
      pload[1] = airPressure & 0xff;
      pload[2] = humidity;
      pload[3] = (brightness >>  16) & 0xff;
      pload[4] = (brightness >>  8) & 0xff;
      pload[5] = brightness & 0xff;
      pload[6] = ((raincounter >> 8) & 0xff) | (israining << 7);
      pload[7] = raincounter & 0xff;
      pload[8] = ((windspeed >> 8) & 0xff) | (winddirrange << 6);
      pload[9] = windspeed & 0xff;
      pload[10] = winddir;
      pload[11] = ((gustspeed >> 8) & 0xff) | (isheating << 7);
      pload[12] = gustspeed & 0xff;
      pload[13] = (uvindex & 0xff) | (lightningdistance << 4);
      pload[14] = lightningcounter & 0xff;
    }
};

class ExtraEventMsg : public Message {
  public:
    void init(uint8_t msgcnt, bool israining, bool isheating, uint16_t gustspeed) {
      Message::init(0x0d, msgcnt, 0x53, BIDI | RPTEN, 0x41, (israining & 0xff) | (isheating << 1));
      pload[0] =  (gustspeed >> 8) & 0xff;
      pload[1] =  gustspeed & 0xff;
    }
};

DEFREGISTER(Reg0, MASTERID_REGS, DREG_TRANSMITTRYMAX, 0x20, 0x21, 0x22, 0x23)
class SensorList0 : public RegList0<Reg0> {
  public:
    SensorList0(uint16_t addr) : RegList0<Reg0>(addr) {}

    bool updIntervall (uint16_t value) const {
      return this->writeRegister(0x20, (value >> 8) & 0xff) && this->writeRegister(0x21, value & 0xff);
    }
    uint16_t updIntervall () const {
      return (this->readRegister(0x20, 0) << 8) + this->readRegister(0x21, 0);
    }

    bool height (uint16_t value) const {
      return this->writeRegister(0x22, (value >> 8) & 0xff) && this->writeRegister(0x23, value & 0xff);
    }
    uint16_t height () const {
      return (this->readRegister(0x22, 0) << 8) + this->readRegister(0x23, 0);
    }

    void defaults () {
      clear();
      updIntervall(60);
      height(0);
      transmitDevTryMax(6);
    }
};

DEFREGISTER(Reg1, 0x01, 0x02, 0x03, 0x04, 0x05, 0x06, 0x07, 0x08, 0x09, 0x0a, 0x0b, 0x0c, 0x0d, 0x0e, 0x0f, 0x10, 0x11, 0x12, 0x13, 0x14, 0x15, 0x16)
class SensorList1 : public RegList1<Reg1> {
  public:
    SensorList1 (uint16_t addr) : RegList1<Reg1>(addr) {}
    bool AnemometerRadius (uint8_t value) const {
      return this->writeRegister(0x01, value & 0xff);
    }
    uint8_t AnemometerRadius () const {
      return this->readRegister(0x01, 0);
    }

    bool AnemometerCalibrationFactor (uint16_t value) const {
      return this->writeRegister(0x02, (value >> 8) & 0xff) && this->writeRegister(0x03, value & 0xff);
    }
    uint16_t AnemometerCalibrationFactor () const {
      return (this->readRegister(0x02, 0) << 8) + this->readRegister(0x03, 0);
    }

    bool LightningDetectorCapacitor (uint8_t value) const {
      return this->writeRegister(0x04, value & 0xff);
    }
    uint8_t LightningDetectorCapacitor () const {
      return this->readRegister(0x04, 0);
    }

    bool LightningDetectorMinStrikes (uint8_t value) const {
      return this->writeRegister(0x12, value & 0xff);
    }
    uint8_t LightningDetectorMinStrikes () const {
      return this->readRegister(0x12, 0);
    }

    bool LightningDetectorWatchdogThreshold (uint8_t value) const {
      return this->writeRegister(0x13, value & 0xff);
    }
    uint8_t LightningDetectorWatchdogThreshold () const {
      return this->readRegister(0x13, 0);
    }

    bool LightningDetectorNoiseFloorLevel (uint8_t value) const {
      return this->writeRegister(0x14, value & 0xff);
    }
    uint8_t LightningDetectorNoiseFloorLevel () const {
      return this->readRegister(0x14, 0);
    }

    bool LightningDetectorSpikeRejection (uint8_t value) const {
      return this->writeRegister(0x15, value & 0xff);
    }
    uint8_t LightningDetectorSpikeRejection () const {
      return this->readRegister(0x15, 0);
    }

    bool LightningDetectorDisturberDetection () const {
      return this->readBit(0x05, 0, true);
    }
    bool LightningDetectorDisturberDetection (bool v) const {
      return this->writeBit(0x05, 0, v);
    }

    bool ExtraMessageOnGustThreshold (uint8_t value) const {
      return this->writeRegister(0x06, value & 0xff);
    }
    uint8_t ExtraMessageOnGustThreshold () const {
      return this->readRegister(0x06, 0);
    }

    bool StormUpperThreshold (uint8_t value) const {
      return this->writeRegister(0x07, value & 0xff);
    }
    uint8_t StormUpperThreshold () const {
      return this->readRegister(0x07, 0);
    }

    bool StormLowerThreshold (uint8_t value) const {
      return this->writeRegister(0x08, value & 0xff);
    }
    uint8_t StormLowerThreshold () const {
      return this->readRegister(0x08, 0);
    }

    bool RaindetectorStallBizHiThresholdRain (uint16_t value) const {
      return this->writeRegister(0x09, (value >> 8) & 0xff) && this->writeRegister(0x0a, value & 0xff);
    }
    uint16_t RaindetectorStallBizHiThresholdRain () const {
      return (this->readRegister(0x09, 0) << 8) + this->readRegister(0x0a, 0);
    }
    bool RaindetectorStallBizLoThresholdRain (uint16_t value) const {
      return this->writeRegister(0x0b, (value >> 8) & 0xff) && this->writeRegister(0x0c, value & 0xff);
    }
    uint16_t RaindetectorStallBizLoThresholdRain () const {
      return (this->readRegister(0x0b, 0) << 8) + this->readRegister(0x0c, 0);
    }
    bool RaindetectorStallBizHiThresholdHeater (uint16_t value) const {
      return this->writeRegister(0x0d, (value >> 8) & 0xff) && this->writeRegister(0x0e, value & 0xff);
    }
    uint16_t RaindetectorStallBizHiThresholdHeater () const {
      return (this->readRegister(0x0d, 0) << 8) + this->readRegister(0x0e, 0);
    }
    bool RaindetectorStallBizLoThresholdHeater (uint16_t value) const {
      return this->writeRegister(0x0f, (value >> 8) & 0xff) && this->writeRegister(0x10, value & 0xff);
    }
    uint16_t RaindetectorStallBizLoThresholdHeater () const {
      return (this->readRegister(0x0f, 0) << 8) + this->readRegister(0x10, 0);
    }

    bool RaindetectorSensorType (uint8_t value) const {
      return this->writeRegister(0x11, value & 0xff);
    }
    uint8_t RaindetectorSensorType () const {
      return this->readRegister(0x11, 0);
    }

    bool RaindetectorStallBizHeatOnDewfall () const {
      return this->readBit(0x16, 0, true);
    }
    bool RaindetectorStallBizHeatOnDewfall (bool v) const {
      return this->writeBit(0x16, 0, v);
    }

    void defaults () {
      clear();
      AnemometerRadius(65);
      AnemometerCalibrationFactor(10);
      LightningDetectorCapacitor(80);
      LightningDetectorDisturberDetection(true);
      ExtraMessageOnGustThreshold(0);
      StormUpperThreshold(0);
      StormLowerThreshold(0);
      RaindetectorSensorType(0);
      RaindetectorStallBizHiThresholdRain(750);
      RaindetectorStallBizLoThresholdRain(500);
      RaindetectorStallBizHiThresholdHeater(500);
      RaindetectorStallBizLoThresholdHeater(400);
      RaindetectorStallBizHeatOnDewfall(true);
      LightningDetectorMinStrikes(0);
      LightningDetectorSpikeRejection(2);
      LightningDetectorWatchdogThreshold(2);
      LightningDetectorNoiseFloorLevel(2);
    }
};

class WeatherChannel : public Channel<Hal, SensorList1, EmptyList, List4, PEERS_PER_CHANNEL, SensorList0>, public Alarm {
    int16_t       temperature;
    uint16_t      airPressure;
    uint8_t       humidity;
    uint32_t      brightness;
    bool          israining;
    bool          isheating;
    uint16_t      raincounter;
    uint16_t      windspeed;
    uint16_t      gustspeed;
    uint16_t      uvindex;
    uint8_t       lightningcounter;
    uint8_t       lightningdistance;

    uint8_t       winddir;
    uint8_t       winddirrange;

    uint16_t      stormUpperThreshold;
    uint16_t      stormLowerThreshold;

    bool          initComplete;
    bool          initLightningDetectorDone;
    uint8_t       short_interval_measure_count;
    uint8_t       israining_alarm_count;

    Sens_Bme280                 bme280;
    Veml6070<VEML6070_1_T>      veml6070;
    MAX44009<>                  max44009;
#ifdef WINDDIRECTION_USE_AS5600
    Sens_As5600                 as5600;
#endif
#ifdef WINDDIRECTION_USE_VENTUSW132
    VentusW132<VENTUSW132_PIN_N, VENTUSW132_PIN_O, VENTUSW132_PIN_S, VENTUSW132_PIN_W> ventus;
#endif
#ifdef WINDDIRECTION_USE_PCF8574
    PCF8574_WindDir<0x38> pcf;
#endif

  public:
#ifdef __SENSORS_AS3935_h__
    Sens_As3935<AS3935_CS_PIN_OR_ADDR, AS3935_IRQ_PIN> as3935;
#endif
  public:
    WeatherChannel () : Channel(), Alarm(seconds2ticks(60)), temperature(0), airPressure(0), humidity(0), brightness(0), israining(false), isheating(false), raincounter(0), windspeed(0), gustspeed(0), uvindex(0), lightningcounter(0), lightningdistance(0), winddir(0), winddirrange(0), stormUpperThreshold(0), stormLowerThreshold(0), initComplete(false), initLightningDetectorDone(false), short_interval_measure_count(0), israining_alarm_count(0), wind_and_uv_measure(*this), lightning_and_raining_check(*this)  {}
    virtual ~WeatherChannel () {}

    class WindSpeedAndUVMeasureAlarm : public Alarm {
        WeatherChannel& chan;
      public:
        WindSpeedAndUVMeasureAlarm (WeatherChannel& c) : Alarm (seconds2ticks(WINDSPEED_MEASUREINTERVAL_SECONDS)), chan(c) {}
        virtual ~WindSpeedAndUVMeasureAlarm () {}

        void trigger (__attribute__ ((unused)) AlarmClock& clock)  {
          chan.measure_windspeed();
          chan.measure_uvindex();
          tick = (seconds2ticks(WINDSPEED_MEASUREINTERVAL_SECONDS));
          clock.add(*this);
          chan.short_interval_measure_count++;
        }
    } wind_and_uv_measure;

    class LightningAndRainingAlarm : public Alarm {
        WeatherChannel& chan;
      public:
        LightningAndRainingAlarm (WeatherChannel& c) : Alarm (seconds2ticks(1)), chan(c) {}
        virtual ~LightningAndRainingAlarm () {}

        void trigger (__attribute__ ((unused)) AlarmClock& clock)  {
          chan.measure_lightning();
          chan.measure_israining();
          tick = (seconds2ticks(1));
          clock.add(*this);
        }
    } lightning_and_raining_check;


    virtual void trigger (__attribute__ ((unused)) AlarmClock& clock) {
      measure_winddirection();
      measure_thpb();
      measure_rainquantity();

      if (initComplete) {
        windspeed = windspeed / short_interval_measure_count;
        if (windspeed > WINDSPEED_MAX) windspeed = WINDSPEED_MAX;
        uvindex = uvindex / short_interval_measure_count;
      }

      //DPRINT(F("GUSTSPEED     : ")); DDECLN(gustspeed);
      //DPRINT(F("WINDSPEED     : ")); DDECLN(windspeed);
      //DPRINT(F("UV Index      : ")); DDECLN(uvindex);
      WeatherEventMsg& msg = (WeatherEventMsg&)device().message();
      uint8_t msgcnt = device().nextcount();
      msg.init(msgcnt, temperature, airPressure, humidity, brightness, israining, isheating, raincounter, windspeed, winddir, winddirrange, gustspeed, uvindex, lightningcounter, lightningdistance);
      if (msgcnt % 20 == 1) {
        device().sendMasterEvent(msg);
      } else {
        device().broadcastEvent(msg);
      }
      uint16_t updCycle = this->device().getList0().updIntervall();
      tick = seconds2ticks(updCycle);

      initComplete = true;
      windspeed = 0;
      gustspeed = 0;
      uvindex = 0;
      short_interval_measure_count = 0;
      sysclock.add(*this);
    }

    void sendExtraMessage (uint8_t t) {
      DPRINT(F("SENDING EXTRA MESSAGE ")); DDECLN(t);
      ExtraEventMsg& extramsg = (ExtraEventMsg&)device().message();
      extramsg.init(device().nextcount(), israining, isheating, gustspeed);
      device().sendMasterEvent(extramsg);
    }

    void measure_windspeed() {
#ifdef NSENSORS
      _wind_isr_counter = random(20);
#endif
      //V = 2 * R * Pi * N
      //  int kmph =  3.141593 * 2 * ((float)anemometerRadius / 100)   * ((float)_wind_isr_counter / (float)WINDSPEED_MEASUREINTERVAL_SECONDS)        * 3.6 * ((float)anemometerCalibrationFactor / 10);
      uint16_t kmph = ((226L * this->getList1().AnemometerRadius() * this->getList1().AnemometerCalibrationFactor() * _wind_isr_counter) / WINDSPEED_MEASUREINTERVAL_SECONDS) / 10000;
      if (kmph > gustspeed) {
        gustspeed = (kmph > GUSTSPEED_MAX) ? GUSTSPEED_MAX : kmph;
      }

      if (this->getList1().ExtraMessageOnGustThreshold() > 0 && kmph > (this->getList1().ExtraMessageOnGustThreshold() * 10)) {
        sendExtraMessage(EVENT_SRC_GUST);
      }

      //DPRINT(F("WIND kmph     : ")); DDECLN(kmph);
      //DPRINT(F("UPPER THRESH  : ")); DDECLN(stormUpperThreshold);
      //DPRINT(F("LOWER THRESH  : ")); DDECLN(stormLowerThreshold);

      static uint8_t STORM_COND_VALUE_Last = STORM_COND_VALUE_LO;
      static uint8_t STORM_COND_VALUE      = STORM_COND_VALUE_LO;

      if (stormUpperThreshold > 0) {
        if (kmph >= stormUpperThreshold || kmph <= stormLowerThreshold) {
          static uint8_t evcnt = 0;

          if (kmph >= stormUpperThreshold) STORM_COND_VALUE = STORM_COND_VALUE_HI;
          if (kmph <= stormLowerThreshold) STORM_COND_VALUE = STORM_COND_VALUE_LO;

          if (STORM_COND_VALUE != STORM_COND_VALUE_Last) {
            SensorEventMsg& rmsg = (SensorEventMsg&)device().message();
            //DPRINT(F("PEER THRESHOLD DETECTED ")); DDECLN(STORM_COND_VALUE);
            rmsg.init(device().nextcount(), number(), evcnt++, STORM_COND_VALUE, false , false);
            device().sendPeerEvent(rmsg, *this);
          }
          STORM_COND_VALUE_Last = STORM_COND_VALUE;
        }
      }

      windspeed += kmph;
      _wind_isr_counter = 0;
    }

    void measure_israining() {
      static bool wasraining = false;

      if (initComplete) {
        if (israining_alarm_count >= RAINDETECTOR_CHECK_INTERVAL) {
          switch (this->getList1().RaindetectorSensorType()) {
            case 0:
              israining = (digitalRead(RAINDETECTOR_PIN) == RAINDETECTOR_PIN_LEVEL_ON_RAIN);
              break;
            case 1:
              digitalWrite(RAINDETECTOR_STALLBIZ_CRG_PIN, HIGH);
              _delay_ms(2);
              digitalWrite(RAINDETECTOR_STALLBIZ_CRG_PIN, LOW);
              uint16_t rdVal = analogRead(RAINDETECTOR_STALLBIZ_SENS_PIN);
              //DPRINT(F("RD aVal       : ")); DDECLN(rdVal);

              if (rdVal > this->getList1().RaindetectorStallBizHiThresholdRain()) {
                israining = true;
              }
              if (rdVal < this->getList1().RaindetectorStallBizLoThresholdRain()) {
                israining = false;
              }

              static bool mustheat = false;
              if (rdVal > this->getList1().RaindetectorStallBizHiThresholdHeater()) {
                mustheat = true;
              }
              if (rdVal < (this->getList1().RaindetectorStallBizLoThresholdHeater())) {
                mustheat = false;
              }

              bool dewfall = false;
              if (this->getList1().RaindetectorStallBizHeatOnDewfall() == true)
                dewfall = bme280.present() ? (abs(bme280.temperature() - bme280.dewPoint()) < RAINDETECTOR_STALLBIZ_HEAT_DEWFALL_T) : false;

              // Heizung schalten
              raindetector_heater(mustheat || dewfall);
          }

          //DPRINT(F("RD israining  : ")); DDECLN(israining);

          if (wasraining != israining) {
            sendExtraMessage(EVENT_SRC_RAINING);
            static uint8_t evcnt = 0;
            SensorEventMsg& rmsg = (SensorEventMsg&)device().message();
            rmsg.init(device().nextcount(), number(), evcnt++, israining ? 200 : 0, true , false);
            device().sendPeerEvent(rmsg, *this);
          }
          wasraining = israining;
          israining_alarm_count = 0;
        }
        israining_alarm_count++;
      }
    }

    void raindetector_heater(bool State) {
      static bool washeating = false;
      static uint8_t pwmval = 0;
      isheating = State;
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
void loop() {
  bool worked = hal.runready();
  bool poll = sdev.pollRadio();
  if ( worked == false && poll == false ) {
    // hal.activity.savePower<Idle<false, true>>(hal);
  }
}

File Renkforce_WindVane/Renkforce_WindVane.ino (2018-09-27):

#include <SoftwareSerial.h>
#define PWM_OUT_PIN   PB4

SoftwareSerial wvSerial(PB3, PB5); // RX, TX

#define START_BYTE            0x2c

//uint8_t directionBytes1[4] = {0x24, 0x64, 0x2c, 0x6c };
//uint8_t directionBytes2[4] = {0x04, 0x0c, 0x01, 0x07 };

uint8_t directionBytes1[4] = {0x26, 0x66, 0x2e, 0x6e };
uint8_t directionBytes2[4] = {0x06, 0x0e, 0x01, 0x07 };

uint8_t receivedValues [4];
uint8_t idx = 0;
uint8_t pwmOutputValue = 0;
uint8_t lastPwmOutputValue = 0;

void setup() {
  wvSerial.begin(2400);
  //wvSerial.print("HELLO");
  pinMode(PWM_OUT_PIN, OUTPUT);
}

void loop() {
  if (wvSerial.available()) {
    uint8_t recv = wvSerial.read();
    if ((recv >> 2) == START_BYTE)  idx = 0;
    receivedValues[idx] = recv;
    //wvSerial.print(receivedValues[idx], HEX);
    //wvSerial.print(" : ");
    idx++;
    if (idx > 2) {
      idx = 0;
      //wvSerial.println("");
    }
  } else {
    if ((receivedValues[0] >> 2) == START_BYTE) {
      if ((receivedValues[1] == directionBytes1[0]) && (receivedValues[2] == directionBytes2[0])) pwmOutputValue = 0;     // N
      if ((receivedValues[1] == directionBytes1[0]) && (receivedValues[2] == directionBytes2[1])) pwmOutputValue = 15;    // NNO
      if ((receivedValues[1] == directionBytes1[0]) && (receivedValues[2] == directionBytes2[2])) pwmOutputValue = 30;    // NO
      if ((receivedValues[1] == directionBytes1[0]) && (receivedValues[2] == directionBytes2[3])) pwmOutputValue = 45;    // ONO

      if ((receivedValues[1] == directionBytes1[1]) && (receivedValues[2] == directionBytes2[0])) pwmOutputValue = 60;    // O
      if ((receivedValues[1] == directionBytes1[1]) && (receivedValues[2] == directionBytes2[1])) pwmOutputValue = 75;    // OSO
      if ((receivedValues[1] == directionBytes1[1]) && (receivedValues[2] == directionBytes2[2])) pwmOutputValue = 90;    // SO
      if ((receivedValues[1] == directionBytes1[1]) && (receivedValues[2] == directionBytes2[3])) pwmOutputValue = 105;   // SSO

      if ((receivedValues[1] == directionBytes1[2]) && (receivedValues[2] == directionBytes2[0])) pwmOutputValue = 120;   // S
      if ((receivedValues[1] == directionBytes1[2]) && (receivedValues[2] == directionBytes2[1])) pwmOutputValue = 135;   // SSW
      if ((receivedValues[1] == directionBytes1[2]) && (receivedValues[2] == directionBytes2[2])) pwmOutputValue = 150;   // SW
      if ((receivedValues[1] == directionBytes1[2]) && (receivedValues[2] == directionBytes2[3])) pwmOutputValue = 165;   // WSW

      if ((receivedValues[1] == directionBytes1[3]) && (receivedValues[2] == directionBytes2[0])) pwmOutputValue = 180;   // W
      if ((receivedValues[1] == directionBytes1[3]) && (receivedValues[2] == directionBytes2[1])) pwmOutputValue = 195;   // WNW
      if ((receivedValues[1] == directionBytes1[3]) && (receivedValues[2] == directionBytes2[2])) pwmOutputValue = 210;   // NW
      if ((receivedValues[1] == directionBytes1[3]) && (receivedValues[2] == directionBytes2[3])) pwmOutputValue = 225;   // NNW

      if (pwmOutputValue != lastPwmOutputValue) {
        analogWrite(PWM_OUT_PIN, pwmOutputValue);
        lastPwmOutputValue = pwmOutputValue;
        //wvSerial.println("pwmOutputValue = " + String(pwmOutputValue));
      }
    }
    idx = 0;
  }
  delay(100);
}

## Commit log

2018-06-03 fixed wind speed calculation
    [HB-UNI-Sen-WEA.ino]
2018-06-03 added sketch to determine winddirection sensor resistor values on analog input
2018-06-04 added wiring diagram
    [wiring.fzz]
2018-06-04 changed wiring diagram
    [wiring.fzz]
2018-06-07 added webui configuration for anemometer radius and calibration factor
2018-06-08 fixed wrong wind speed calculation removed BIDI message every 20 BCAST
    [HB-UNI-Sen-WEA.ino]
2018-06-17 added VEML6070 uv sensor
2018-06-17 removed two wrong resistors
    [wiring.fzz]
2018-06-17 - added support for uv sensor VEML6070 - added support for lightning detection (future use, not implemented yet)
2018-06-21 switched to LibSPI implemented AS3935 with SPI
2018-06-28 added As3935 Sensor Class
2018-06-30 added lightning sensor
2018-06-30 added 2 new registers in List1 - AS3935 Capacitor - AS3935 Disturber Detection
2018-06-30 added 2 new registers in List1 - AS3935 Capacitor - AS3935 Disturber Detection some changes for AS3935
2018-07-04 added support for MAX44009 ambient light sensor
2018-07-04 added sketch to find the best capacitor value for AS3935
2018-07-04 - added MAX44009 ambient light sensor - memory optimization
2018-07-04 removed Max44009 sensor class; now included in AskSinPP Lib
2018-07-04 removed separate Veml6070 sensor class
2018-07-05 renamed Sens_Veml6070 to Veml6070 to match sensor class
2018-07-08 changed wiring and added some images
    [wiring.fzz]
2018-07-12 removed some debug messages corrected lightning distance calc
    [HB-UNI-Sen-WEA.ino]
2018-07-12 changed wiring image
    [wiring.fzz]
2018-07-14 changed values for the resistor circle in wiring diagram
2018-07-15 fixed error in wiring
    [wiring.fzz]
2018-07-18 shortened debug messages (reduces sketch size) added environment calculations for absolute humidity and dewpoint
    [Sens_Bme280.h]
2018-07-22 changed wiring, support rain detector from stall.biz
    [wiring.fzz]
2018-07-22 commented out some debug messages to reduce flash size added peering for rain detection and gust added support for rain detector from stall.biz
    [HB-UNI-Sen-WEA.ino]
2018-07-23 updates wiring
    [wiring.fzz]
2018-07-23 fixed wrong fake values for lightning counter
    [HB-UNI-Sen-WEA.ino]
2018-07-27 - fixed overrun of raincounter and windspeed - renamed some variable names - added comments for better understanding -
    [HB-UNI-Sen-WEA.ino]
2018-07-27 fixed max value for gust speed
    [HB-UNI-Sen-WEA.ino]
2018-07-27 transmit rain detector heating state to ccu
2018-07-27 use new device firmware file
2018-07-28 modified analog threshold values for stall.biz rain detector
    [HB-UNI-Sen-WEA.ino]
2018-07-28 added thresholds for rain detection and heater
2018-07-30 include LowPower.h for compatibility issues
    [HB-UNI-Sen-WEA.ino]
2018-07-30 added definitions for HI und LO thresholds for analog values of stall.biz rain detector
    [HB-UNI-Sen-WEA.ino]
2018-07-30 extra event frame for extra messages
2018-08-01 moved files and added stevensson screen
    [01Anem_Cup.stl, 02Anem_center.stl, 03Anem_Base.stl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]
2018-08-05 updated wiring scheme
    [wiring.fzz]
2018-08-07 added WebUI configuration parameters for lightning detector and stall.biz rain detector new firmware version 1.4 (0x14)
    [HB-UNI-Sen-WEA.ino]
2018-08-08 added SENSOR_ONLY define, to reduce flash size with latest AskSinPP Lib
2018-08-22 fixed wrong upper/lower storm threshold
    [HB-UNI-Sen-WEA.ino]
2018-08-26 slightly start the heater to avoid voltage drop
    [HB-UNI-Sen-WEA.ino]
2018-08-29 change heating on dewfall from webui
2020-01-03 add As5600 sensor class for wind direction measurement
2020-03-10 RaindetectorStallBizTest: test the heating as well
2020-03-10 remove redundant setting for pin 3 (IRQpin)
2020-06-07 update pin order
2020-06-12 add support for I2C connected AS3935 sensor
2020-06-27 add I2C files needed by AS3935 I2C sensor
